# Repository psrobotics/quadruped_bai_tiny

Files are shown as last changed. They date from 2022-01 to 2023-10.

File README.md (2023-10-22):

# Quadruped_bai_tiny v1

Still working on detailed document.

quad_servo_cad

## Videos

[Walking](https://youtu.be/wHSh3s8Uc68)  /  [Jumping](https://youtu.be/LqSfARLMR58)  /  [Leg demo](https://www.youtube.com/watch?v=xufyeLivXR8)

## File Structure

* /hardware - CAD design

* /electronic - Motor driver, Main controller brd, Encoder brd, IIC bridge brd

* /sim - V-rep simulation, Kinematics, Dynamics

* /software - Firmware

## Reducer
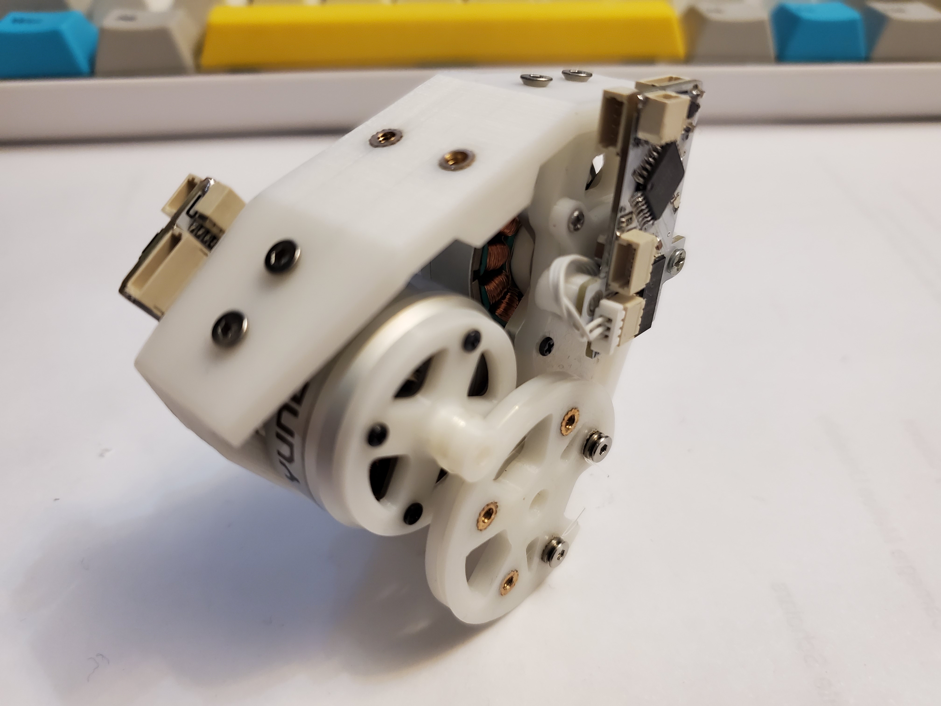
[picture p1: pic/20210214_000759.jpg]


## Leg Assembly
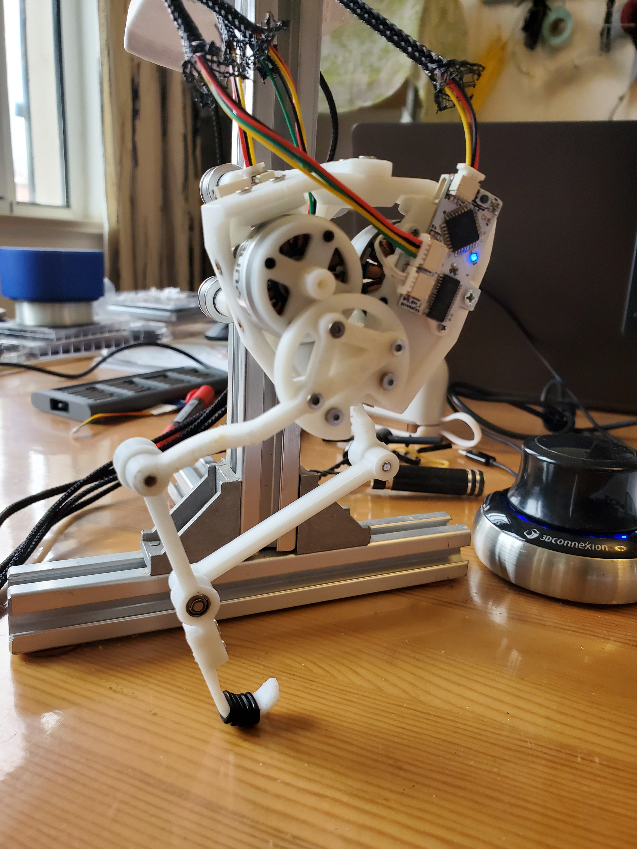
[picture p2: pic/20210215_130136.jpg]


## Body Assembly
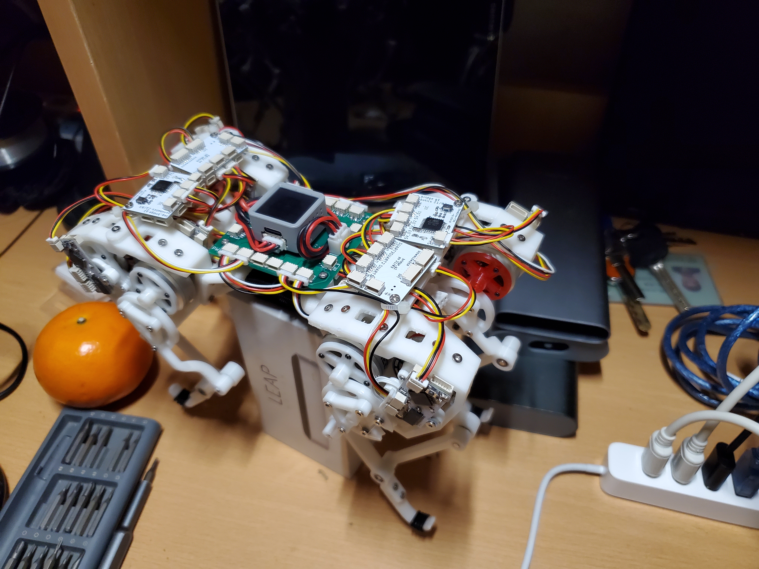
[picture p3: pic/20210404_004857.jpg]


## Motor Driver
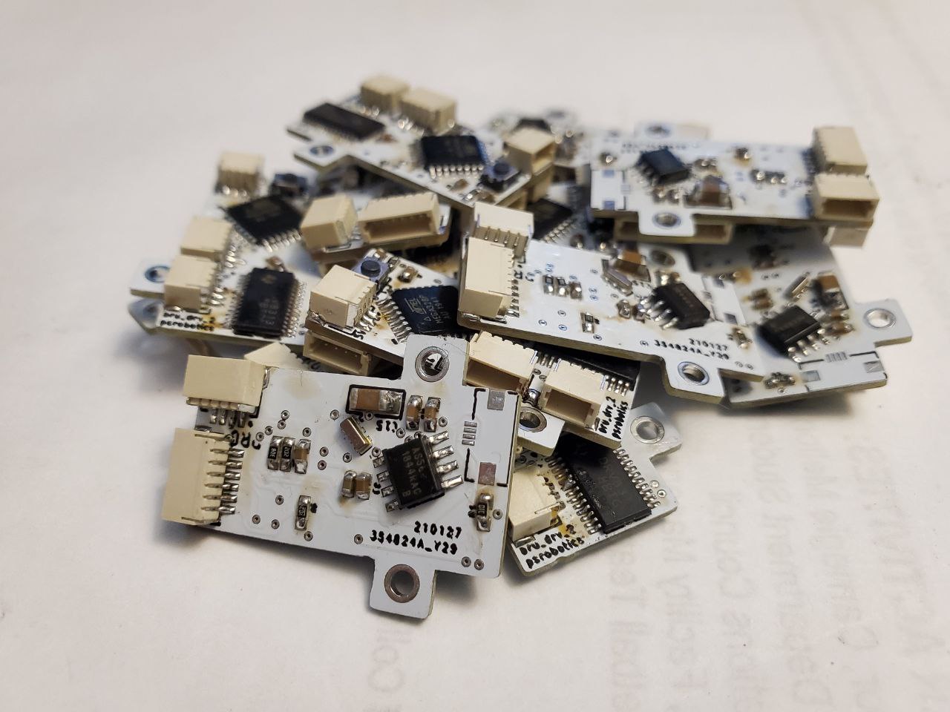
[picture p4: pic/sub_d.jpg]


## Main Controller
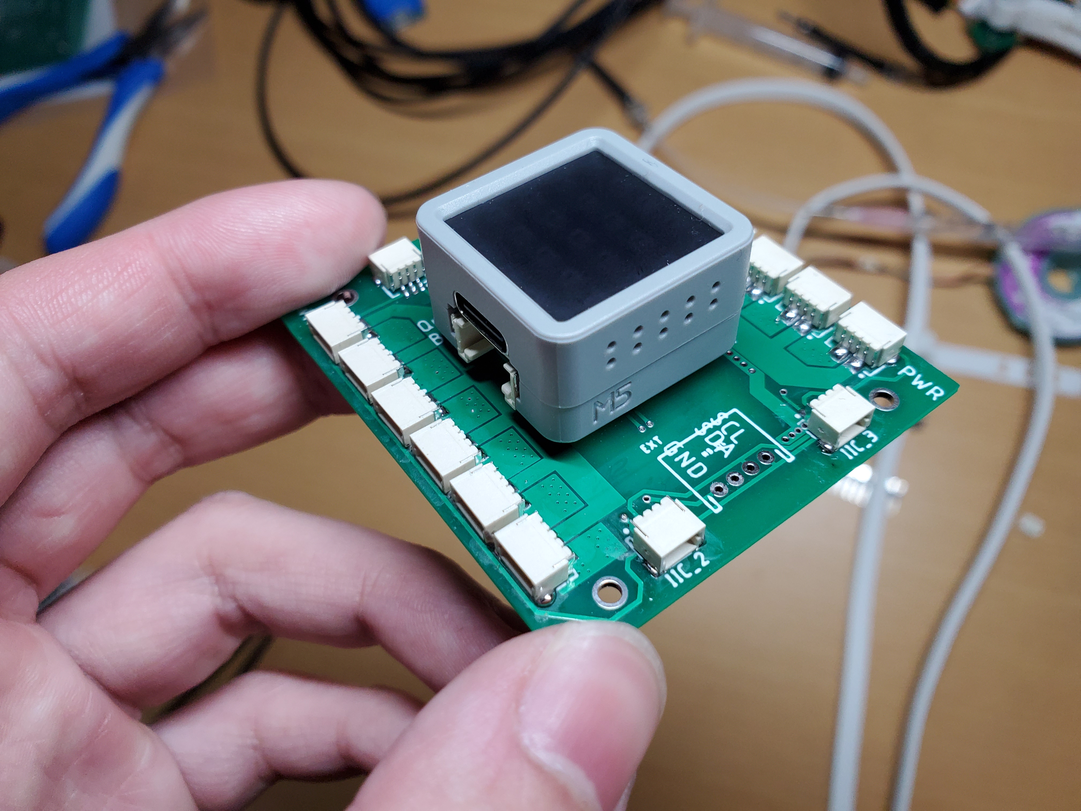
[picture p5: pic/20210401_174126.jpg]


## License
MIT License

## Contact
* Shuang Peng, {shuangpe}@usc.edu

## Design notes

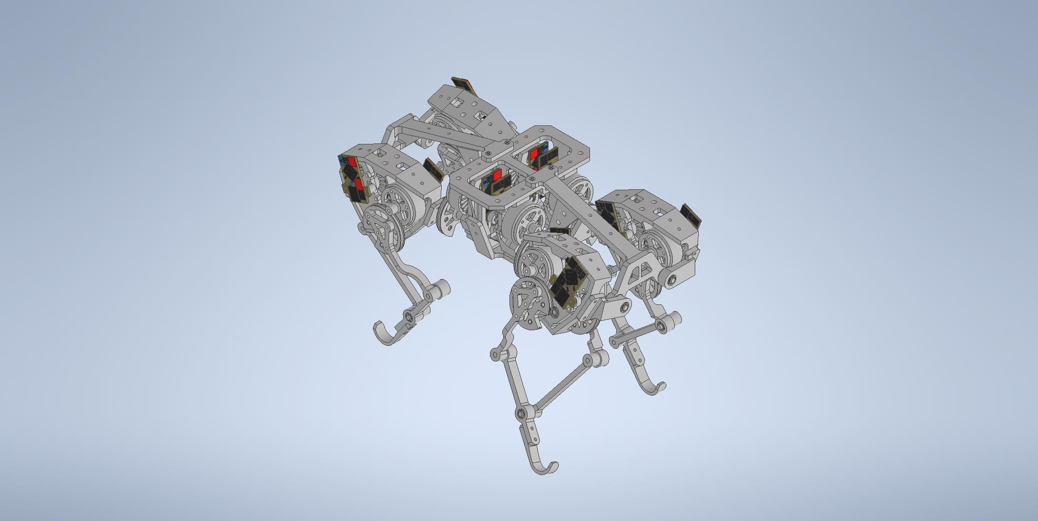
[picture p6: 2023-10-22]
hardware/pic_export/body_1.jpg

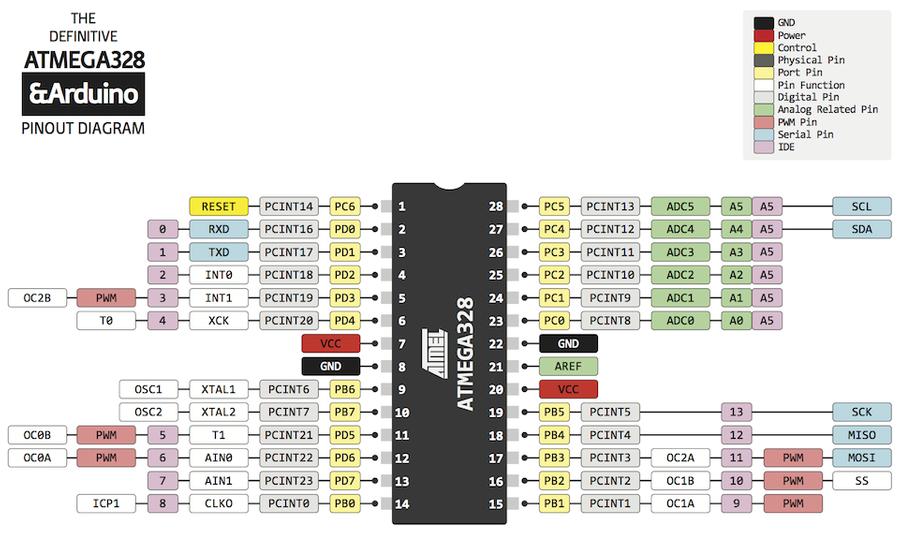
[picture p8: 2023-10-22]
electronic/ref/Atmega328P-PU-met-Arduino-Optiboot-(Arduino-Uno).jpg

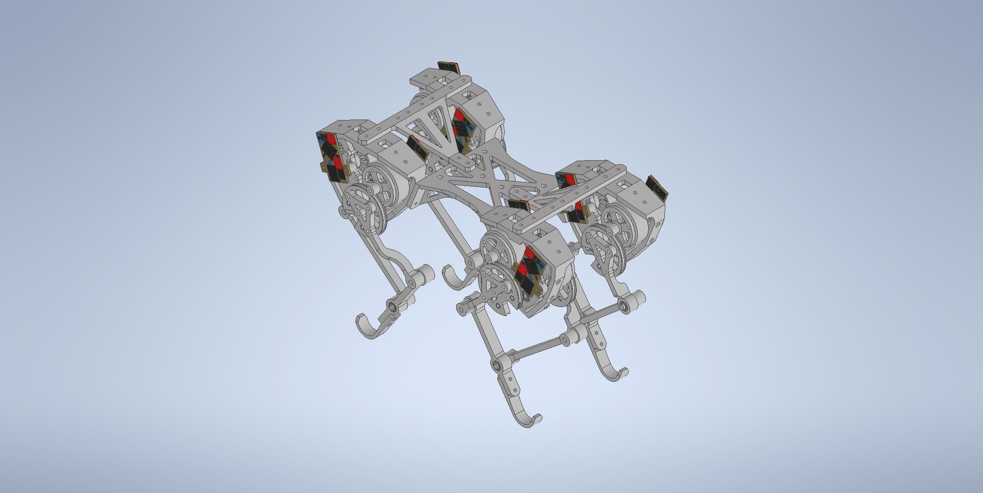
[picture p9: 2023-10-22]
hardware/pic_export/body_8d_1.jpg

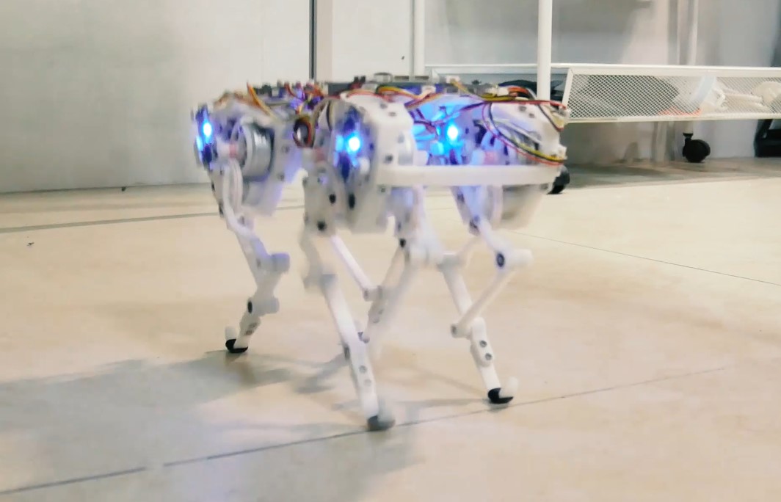
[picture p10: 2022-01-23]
pic/quad_bai_tiny_1.jpg

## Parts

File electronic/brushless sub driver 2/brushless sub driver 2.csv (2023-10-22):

RefDes | Value | Device | Package | Description | ARROW_EUROPE-PURCHASE-URL | AVAILABILITY | BUILT_BY | DESCRIPTION | DIGI-KEY_PART_NUMBER | DIGI-KEY_PURCHASE_URL | DIGIKEY-PURCHASE-URL | HEIGHT | MANUFACTURER_NAME | MANUFACTURER_PART_NUMBER | MF | MOUSER_PART_NUMBER | MOUSER_PRICE-STOCK | MP | PACKAGE | PRICE | PROD_ID | RS_PART_NUMBER | RS_PRICE-STOCK | SOURCELIBRARY | VALUE | VENDOR
5V | SM03B-SRSS-TB(LF)(SN) | SM03B-SRSS-TB(LF)(SN) | JST_SM03B-SRSS-TB(LF)(SN) | SH Series 3 Position 1 mm Pitch Surface Mount Side Entry Shrouded Header |  | Unavailable |  | Connector Header Surface Mount, Right Angle 3 position 0.039 _1.00mm_ |  |  |  |  |  |  | JST Sales |  |  | SM03B-SRSS-TB_LF__SN_ | None | None
C1 | 0.1uF | CAP0603-CAP | 0603-CAP | Capacitor
C2 | 0.1uF | CAP0603-CAP | 0603-CAP | Capacitor
C3 | 10nF | 10NF-0603-50V-10% | 0603 | 0.01uF/10nF/10,000pF ceramic capacitors |  |  |  |  |  |  |  |  |  |  |  |  |  |  |  |  | CAP-00867 |  |  |  | 10nF
C4 | 0.1uF | 0.1UF-0603-25V-(+80/-20%) | 0603 | 0.1µF ceramic capacitors |  |  |  |  |  |  |  |  |  |  |  |  |  |  |  |  | CAP-00810 |  |  |  | 0.1uF
C5 | 470nF | 470NF-0603-10V-10%-X5R | 0603 | 0.47uF/470nF ceramic capacitors |  |  |  |  |  |  |  |  |  |  |  |  |  |  |  |  | CAP-13216 |  |  |  | 470nF
C8 | 0.1uF | 0.1UF-0402-16V-10% | 0402 | 0.1µF ceramic capacitors |  |  |  |  |  |  |  |  |  |  |  |  |  |  |  |  | CAP-12416 |  |  |  | 0.1uF
C9 | 1.0uF | 1.0UF-0402-16V-10% | 0402 | 1µF ceramic capacitors |  |  |  |  |  |  |  |  |  |  |  |  |  |  |  |  | CAP-12417 |  |  |  | 1.0uF
C11 | 0.1uF | CAP0603-CAP | 0603-CAP | Capacitor
C15 | 100uf | C_1206 | C1206 | NON-POLARIZED CAP
D1 | b | LED0603 | LED-0603 | LED (Generic)
EN_EXT | 54550-0494 | 54550-0494 | CON4_1X4_DRB2_MOL |  |  |  | EMA_UL_Team |  |  |  |  |  |  | 54550-0494 |  |  |  |  |  |  |  |  |  | Molex_2010-01-01 |  | Molex Connector Corporation
IC1 | AS5600-ASOT | AS5600-ASOT | SOIC127P600X175-8N | Board Mount Hall Effect / Magnetic Sensors AS5600 Magnetic Sensor 12-Bit |  |  |  | Board Mount Hall Effect / Magnetic Sensors AS5600 Magnetic Sensor 12-Bit |  |  |  | 1.75mm | ams | AS5600-ASOT |  | 985-AS5600-ASOT | https://www.mouser.com/Search/Refine.aspx?Keyword=985-AS5600-ASOT
MOT | SM03B-SRSS-TB(LF)(SN) | SM03B-SRSS-TB(LF)(SN) | JST_SM03B-SRSS-TB(LF)(SN) | SH Series 3 Position 1 mm Pitch Surface Mount Side Entry Shrouded Header |  | Unavailable |  | Connector Header Surface Mount, Right Angle 3 position 0.039 _1.00mm_ |  |  |  |  |  |  | JST Sales |  |  | SM03B-SRSS-TB_LF__SN_ | None | None
NEFI | SM06B-SRSS-TB | SM06B-SRSS-TB | SM06B | CONN HEADER SH 6POS SIDE 1MM TIN Check prices |  | Bad |  | Connector Header Surface Mount, Right Angle 6 position 0.039 (1.00mm) |  |  |  |  |  |  | JST Sales |  |  | SM06B-SRSS-TB | None | None
PRO | SM04B-SRSS-TB(LF)(SN) | SM04B-SRSS-TB(LF)(SN) | JST_SM04B-SRSS-TB(LF)(SN) | SH Series 1.0 mm Pitch 2 Position Single Row Side Entry Shrouded Header Check prices | https://snapeda.com/shop?store=Arrow+Europe&id=557466 | Good |  | Connector Header Surface Mount, Right Angle 4 position 0.039 (1.00mm) |  |  | https://snapeda.com/shop?store=DigiKey&id=557466 |  |  |  | JST Sales |  |  | SM04B-SRSS-TB(LF)(SN) | None | None
PWR | SM04B-SRSS-TB(LF)(SN) | SM04B-SRSS-TB(LF)(SN) | JST_SM04B-SRSS-TB(LF)(SN) | SH Series 1.0 mm Pitch 2 Position Single Row Side Entry Shrouded Header Check prices | https://snapeda.com/shop?store=Arrow+Europe&id=557466 | Good |  | Connector Header Surface Mount, Right Angle 4 position 0.039 (1.00mm) |  |  | https://snapeda.com/shop?store=DigiKey&id=557466 |  |  |  | JST Sales |  |  | SM04B-SRSS-TB(LF)(SN) | None | None
Q2 | 16mhz | RESONATOR-MURATACST_CE | RESONATOR_MURATA2 | Murata ceramic Resonator ceralock" CSTCE series"
R1 | 10k | 10KOHM-0603-1/10W-1% | 0603 | 10kΩ resistor |  |  |  |  |  |  |  |  |  |  |  |  |  |  |  |  | RES-00824 |  |  |  | 10k
R2 | 10K | RESISTOR0603-RES | 0603-RES | Resistor
R3 | 2.2k | RESISTOR0603-RES | 0603-RES | Resistor
R4 | 0 | R_0603 | R0603 | RESISTOR
R5 | 3K | RESISTOR0603-RES | 0603-RES | Resistor
R8 | 2.2k | RESISTOR0603-RES | 0603-RES | Resistor
S2 | MOMENTARY-SWITCH-SPST-SMD-RIGHT-ANGLE | MOMENTARY-SWITCH-SPST-SMD-RIGHT-ANGLE | TACTILE_SWITCH_SMD_RIGHT_ANGLE | Momentary Switch (Pushbutton) - SPST |  |  |  |  |  |  |  |  |  |  |  |  |  |  |  |  | COMP-12265
U1 | DRV8313PWP | DRV8313PWP | SOP28P65_970X640X120L60X24T483X275N | 2.5A Three Phase Brushless DC Motor Driver (PWM Ctrl) 28-HTSSOP -40 to 85 |  |  |  | 2.5A Three Phase Brushless DC Motor Driver _PWM Ctrl_ 28-HTSSOP -40 to 85 | 296-35540-5-ND | https://www.digikey.com.cn/product-detail/zh/texas-instruments/DRV8313PWP/296-35540-5-ND/3790947 |  |  |  |  | Texas Instruments |  |  | DRV8313PWP | HTSSOP-28 Texas Instruments
U3 | ATMEGA328 | ATMEGA168 | TQFP32-08

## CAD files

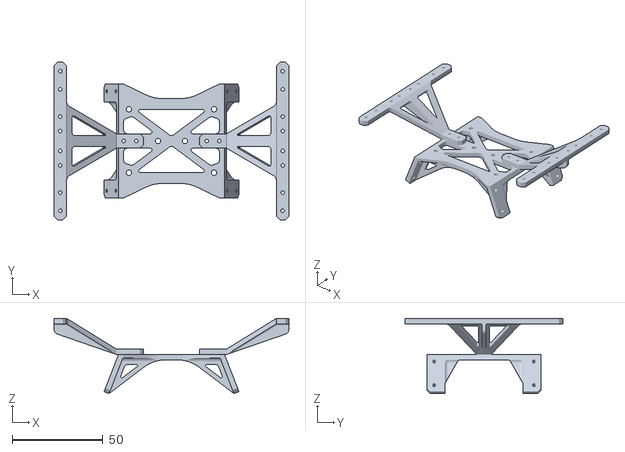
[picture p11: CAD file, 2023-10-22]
hardware/sim_mod/8dof_body.stl
129.8 x 87.0 x 41.5

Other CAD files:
hardware/8dof_body.iam
hardware/OldVersions/8dof_body.0001.iam
hardware/OldVersions/bearing_3_6_2.0007.ipt
hardware/OldVersions/bearing_3_6_2_MIR.0001.ipt
hardware/OldVersions/body_1.0043.iam
hardware/OldVersions/body_8d_1.0019.iam
hardware/OldVersions/body_8d_wid_1.0006.iam
hardware/OldVersions/body_conn_1.0007.ipt
hardware/OldVersions/body_conn_1_MIR.0002.ipt
hardware/OldVersions/body_conn_2.0006.ipt
hardware/OldVersions/body_conn_2_MIR.0002.ipt
hardware/OldVersions/body_linker_1_8d.0004.ipt
hardware/OldVersions/body_linker_1_wid_8d.0008.ipt
hardware/OldVersions/body_linker_2_8d.0004.ipt
hardware/OldVersions/body_linker_2_8d_wid.0004.ipt
hardware/OldVersions/body_shell_1.0009.ipt
hardware/OldVersions/body_shell_2.0008.ipt
hardware/OldVersions/cable_shell_1.0001.ipt
hardware/OldVersions/en_shell_1.0003.ipt
hardware/OldVersions/enc_holder_1.0004.ipt
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

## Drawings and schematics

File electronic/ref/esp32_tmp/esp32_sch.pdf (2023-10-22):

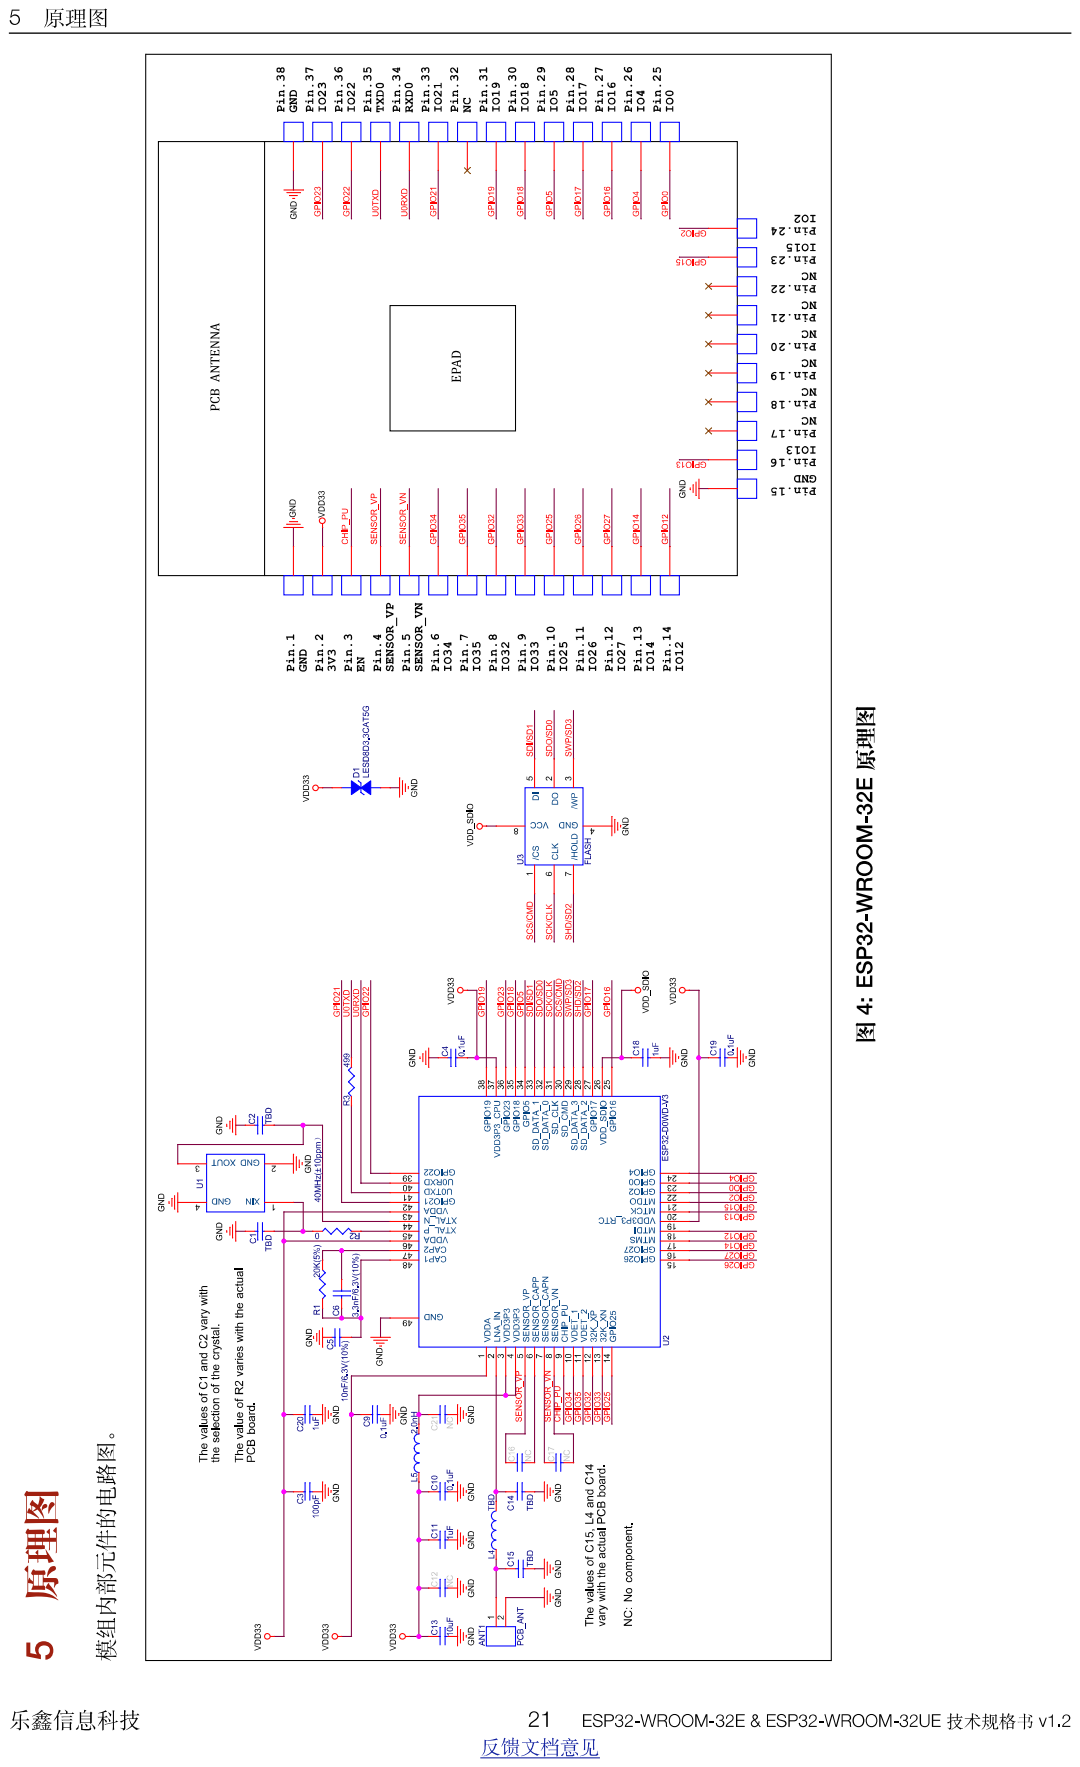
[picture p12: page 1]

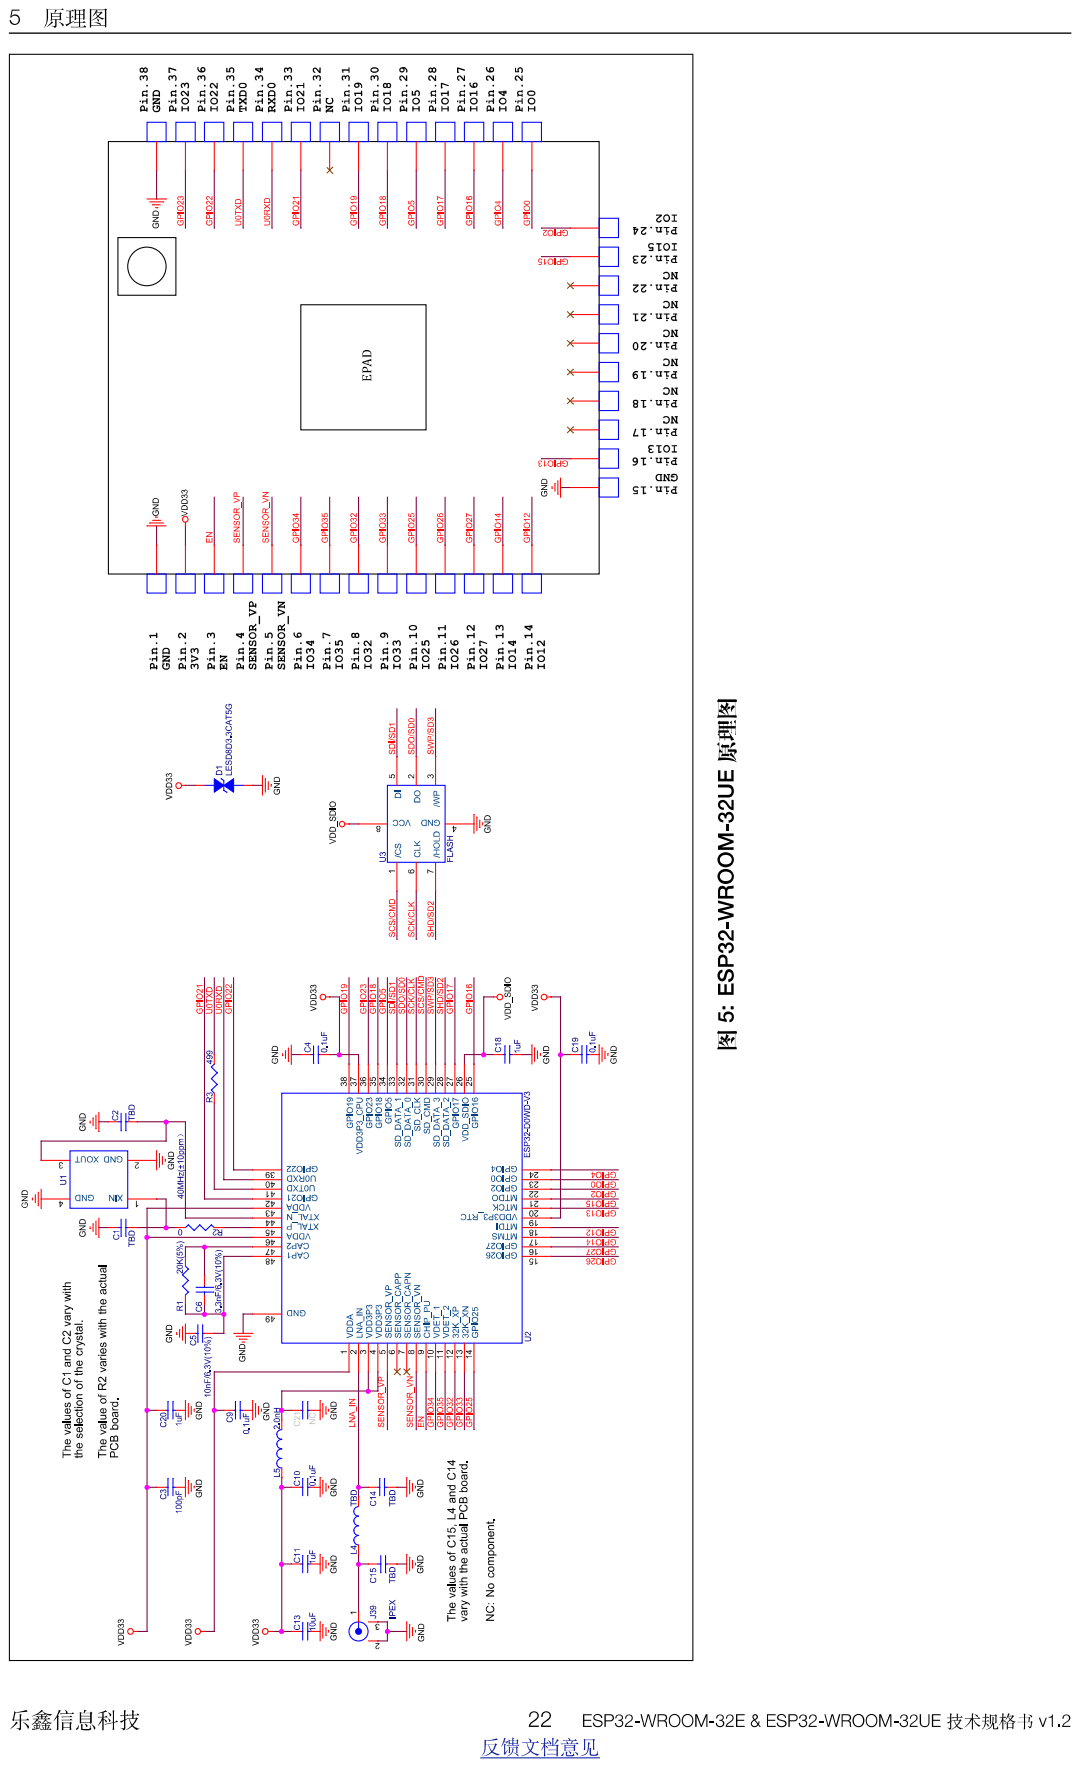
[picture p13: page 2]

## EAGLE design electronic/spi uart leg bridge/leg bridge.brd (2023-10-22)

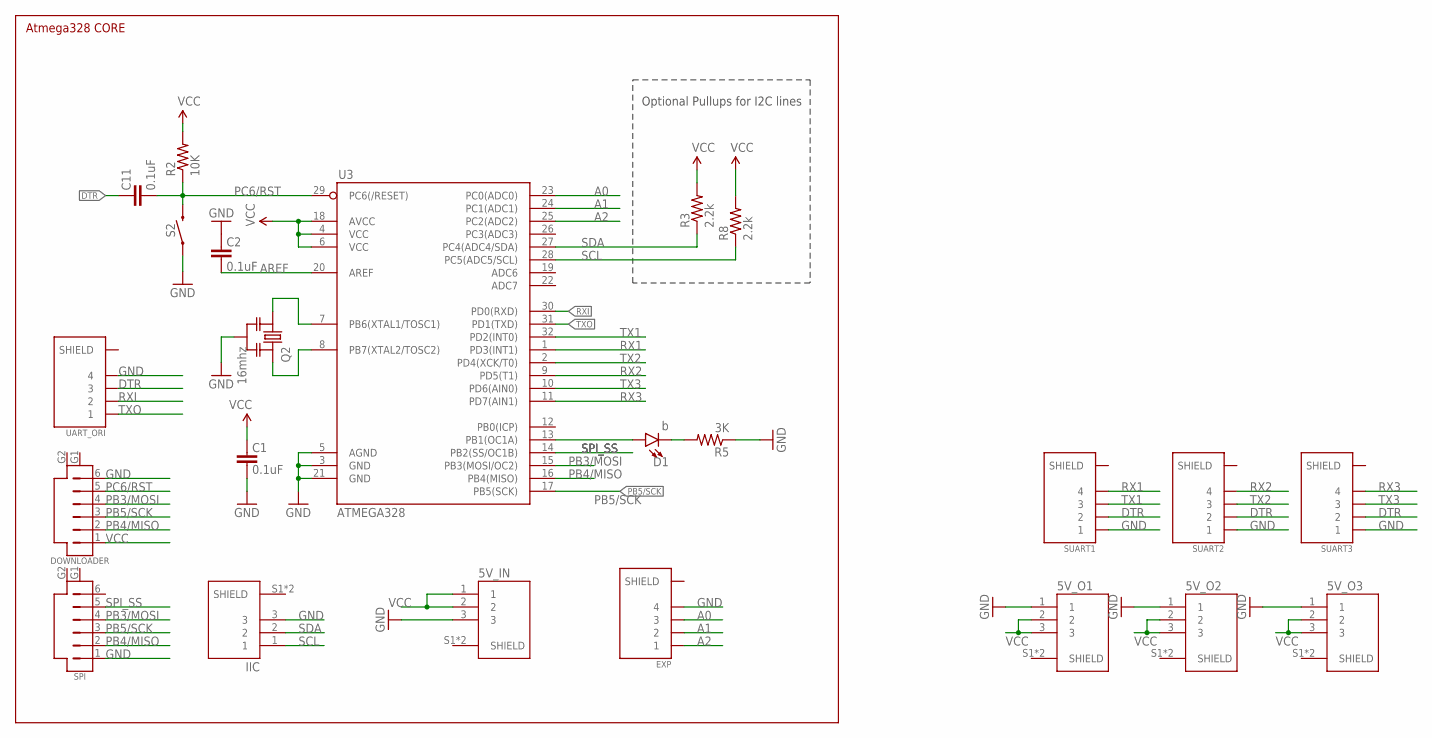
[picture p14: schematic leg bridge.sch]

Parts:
5V_IN, 5V_O1, 5V_O2, 5V_O3: SM03B-SRSS-TB(LF)(SN); JST_SM03B-SRSS-TB(LF)(SN)
C1, C2, C11: 0.1uF; 0603-CAP
D1: b; LED-0603
DOWNLOADER: SM06B-SRSS-TB; SM06B
EXP: SM04B-SRSS-TB(LF)(SN); JST_SM04B-SRSS-TB(LF)(SN)
IIC: SM03B-SRSS-TB(LF)(SN); JST_SM03B-SRSS-TB(LF)(SN)
Q2: 16mhz; RESONATOR_MURATA2
R2: 10K; 0603-RES
R3, R8: 2.2k; 0603-RES
R5: 3K; 0603-RES
S2: MOMENTARY-SWITCH-SPST-SMD-RIGHT-ANGLE; TACTILE_SWITCH_SMD_RIGHT_ANGLE
SPI: SM06B-SRSS-TB; SM06B
SUART1, SUART2, SUART3: SM04B-SRSS-TB(LF)(SN); JST_SM04B-SRSS-TB(LF)(SN)
U3: ATMEGA328; TQFP32-08
UART_ORI: SM04B-SRSS-TB(LF)(SN); JST_SM04B-SRSS-TB(LF)(SN)

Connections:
A0: EXP.3, U3.23 (PC0(ADC0))
A1: EXP.2, U3.24 (PC1(ADC1))
A2: EXP.1, U3.25 (PC2(ADC2))
AREF: C2.1, U3.20 (AREF)
DTR: C11.2, SUART1.2, SUART2.2, SUART3.2, UART_ORI.3
GND: 5V_IN.3, 5V_O1.1, 5V_O2.1, 5V_O3.1, C1.1, C2.2, DOWNLOADER.6, EXP.4, IIC.3, Q2.2, R5.1, S2.1, SPI.1, SUART1.1, SUART2.1, SUART3.1, U3.3 (GND), U3.5 (AGND), U3.21 (GND), UART_ORI.4
unnamed: Q2.1, U3.7 (PB6(XTAL1/TOSC1))
unnamed: Q2.3, U3.8 (PB7(XTAL2/TOSC2))
unnamed: D1.A, U3.13 (PB1(OC1A))
unnamed: D1.C, R5.2
PB3/MOSI: DOWNLOADER.4, SPI.4, U3.15 (PB3(MOSI/OC2))
PB4/MISO: DOWNLOADER.2, SPI.2, U3.16 (PB4(MISO))
PB5/SCK: DOWNLOADER.3, SPI.3, U3.17 (PB5(SCK))
PC6/RST: C11.1, DOWNLOADER.5, R2.1, S2.2, U3.29 (PC6(/RESET))
RX1: SUART1.4, U3.1 (PD3(INT1))
RX2: SUART2.4, U3.9 (PD5(T1))
RX3: SUART3.4, U3.11 (PD7(AIN1))
RXI: U3.30 (PD0(RXD)), UART_ORI.2
SCL: IIC.1, R8.1, U3.28 (PC5(ADC5/SCL))
SDA: IIC.2, R3.1, U3.27 (PC4(ADC4/SDA))
SPI_SS: SPI.5, U3.14 (PB2(SS/OC1B))
TX1: SUART1.3, U3.32 (PD2(INT0))
TX2: SUART2.3, U3.2 (PD4(XCK/T0))
TX3: SUART3.3, U3.10 (PD6(AIN0))
TXO: U3.31 (PD1(TXD)), UART_ORI.1
VCC: 5V_IN.1, 5V_IN.2, 5V_O1.2, 5V_O1.3, 5V_O2.2, 5V_O2.3, 5V_O3.2, 5V_O3.3, C1.2, DOWNLOADER.1, R2.2, R3.2, R8.2, U3.4 (VCC), U3.6 (VCC), U3.18 (AVCC)

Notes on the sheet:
Optional Pullups for I2C lines
Atmega328 CORE

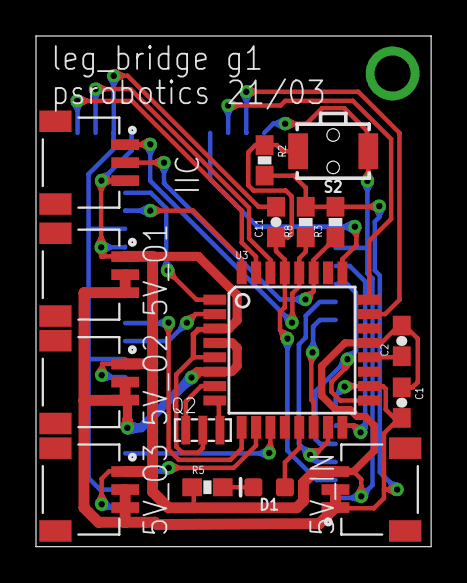
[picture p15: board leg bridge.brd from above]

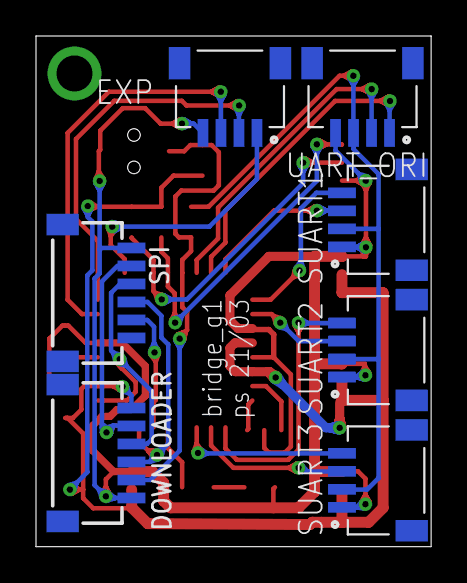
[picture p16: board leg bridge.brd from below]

Board: 2 copper layers, 22.0 x 28.4 mm, 23 parts (7 on the bottom side), 26 nets.

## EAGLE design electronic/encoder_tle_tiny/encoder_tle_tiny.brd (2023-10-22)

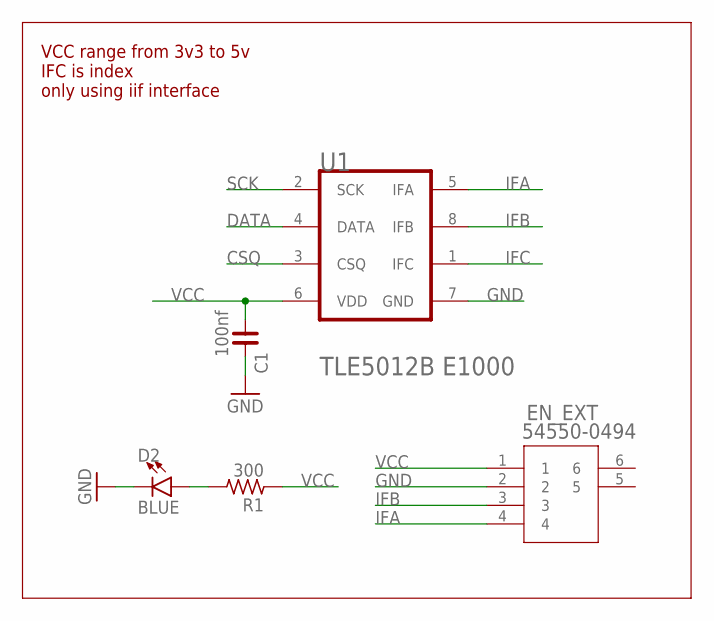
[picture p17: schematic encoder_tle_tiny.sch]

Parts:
C1: 100nf; C0603
D2: BLUE; LED-0603
EN_EXT: 54550-0494; CON4_1X4_DRB2_MOL
R1: 300; R0603
U1: INFINEON_TLE5012B_E1000INFINEON_TLE5012B_E1000_0_1; INFINEON_TLE5012B_E1000_1

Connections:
CSQ: U1.3 (CSQ)
DATA: U1.4 (DATA)
GND: C1.2, D2.C, EN_EXT.2, U1.7 (GND)
IFA: EN_EXT.4, U1.5 (IFA)
IFB: EN_EXT.3, U1.8 (IFB)
IFC: U1.1 (IFC)
unnamed: D2.A, R1.2
SCK: U1.2 (SCK)
VCC: C1.1, EN_EXT.1, R1.1, U1.6 (VDD)

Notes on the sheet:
VCC range from 3v3 to 5v IFC is index only using iif interface

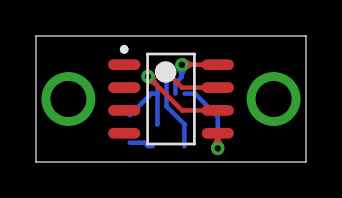
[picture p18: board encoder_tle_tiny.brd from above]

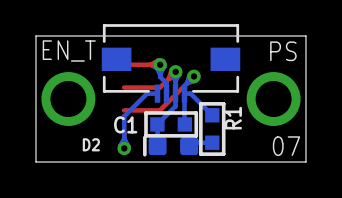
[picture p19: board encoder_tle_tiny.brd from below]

Board: 2 copper layers, 15.0 x 7.0 mm, 5 parts (4 on the bottom side), 5 nets.

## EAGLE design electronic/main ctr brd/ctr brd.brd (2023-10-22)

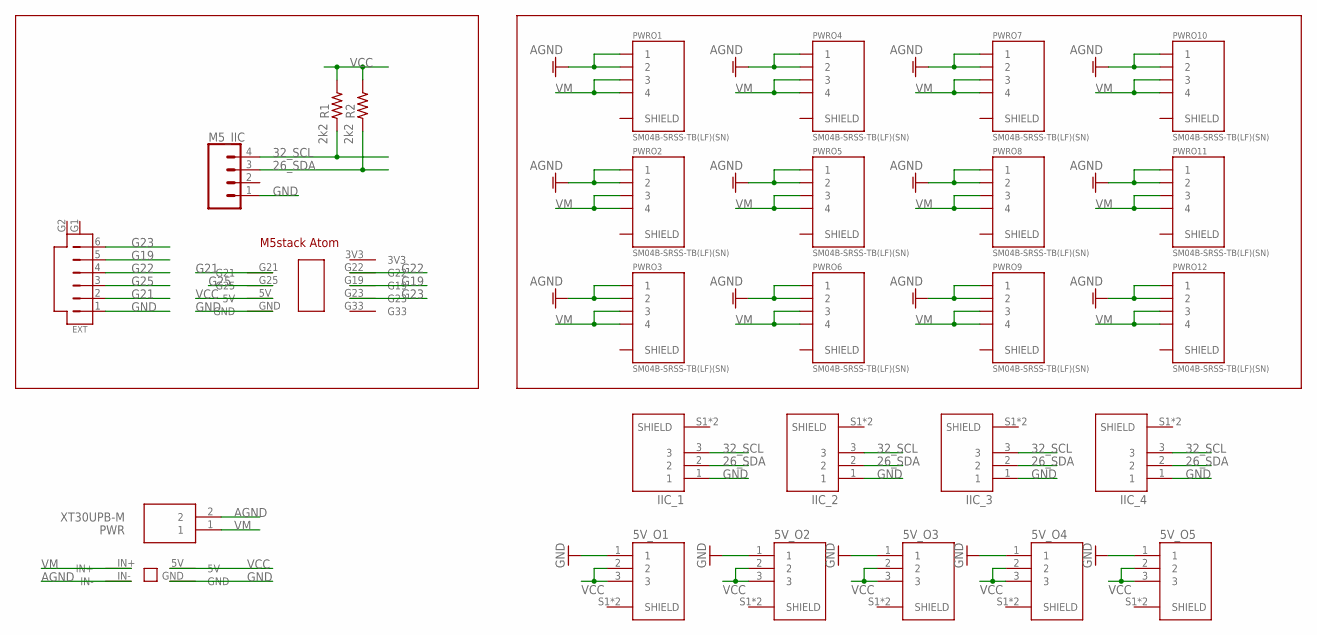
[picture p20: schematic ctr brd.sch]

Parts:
5V_O1, 5V_O2, 5V_O3, 5V_O4, 5V_O5: SM03B-SRSS-TB(LF)(SN); JST_SM03B-SRSS-TB(LF)(SN)
EXT: SM06B-SRSS-TB; SM06B
IIC_1, IIC_2, IIC_3, IIC_4: SM03B-SRSS-TB(LF)(SN); JST_SM03B-SRSS-TB(LF)(SN)
M5_IIC: CONN_04JST-PTH; JST-4-PTH
PWR: XT30UPB-M; SHDR2W160P0X500_1X2_1020X520X1
PWRO1, PWRO2, PWRO3, PWRO4, PWRO5, PWRO6, PWRO7, PWRO8, PWRO9, PWRO10, PWRO11, PWRO12: SM04B-SRSS-TB(LF)(SN); JST_SM04B-SRSS-TB(LF)(SN)
R1, R2: 2k2; R0603
U$1: M5STACK_ATOM
U$2: 5V_STAB

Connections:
26_SDA: IIC_1.2, IIC_2.2, IIC_3.2, IIC_4.2, M5_IIC.3, R2.1
32_SCL: IIC_1.3, IIC_2.3, IIC_3.3, IIC_4.3, M5_IIC.4, R1.1
AGND: PWR.2, PWRO1.1, PWRO1.2, PWRO2.1, PWRO2.2, PWRO3.1, PWRO3.2, PWRO4.1, PWRO4.2, PWRO5.1, PWRO5.2, PWRO6.1, PWRO6.2, PWRO7.1, PWRO7.2, PWRO8.1, PWRO8.2, PWRO9.1, PWRO9.2, PWRO10.1, PWRO10.2, PWRO11.1, PWRO11.2, PWRO12.1, PWRO12.2, U$2.IN-
G19: EXT.5, U$1.G19
G21: EXT.2, U$1.G21
G22: EXT.4, U$1.G22
G23: EXT.6, U$1.G23
G25: EXT.3, U$1.G25
GND: 5V_O1.1, 5V_O2.1, 5V_O3.1, 5V_O4.1, 5V_O5.1, EXT.1, IIC_1.1, IIC_2.1, IIC_3.1, IIC_4.1, M5_IIC.1, U$1.GND, U$2.GND
VCC: 5V_O1.2, 5V_O1.3, 5V_O2.2, 5V_O2.3, 5V_O3.2, 5V_O3.3, 5V_O4.2, 5V_O4.3, 5V_O5.2, 5V_O5.3, R1.2, R2.2, U$1.5V, U$2.5V
VM: PWR.1, PWRO1.3, PWRO1.4, PWRO2.3, PWRO2.4, PWRO3.3, PWRO3.4, PWRO4.3, PWRO4.4, PWRO5.3, PWRO5.4, PWRO6.3, PWRO6.4, PWRO7.3, PWRO7.4, PWRO8.3, PWRO8.4, PWRO9.3, PWRO9.4, PWRO10.3, PWRO10.4, PWRO11.3, PWRO11.4, PWRO12.3, PWRO12.4, U$2.IN+

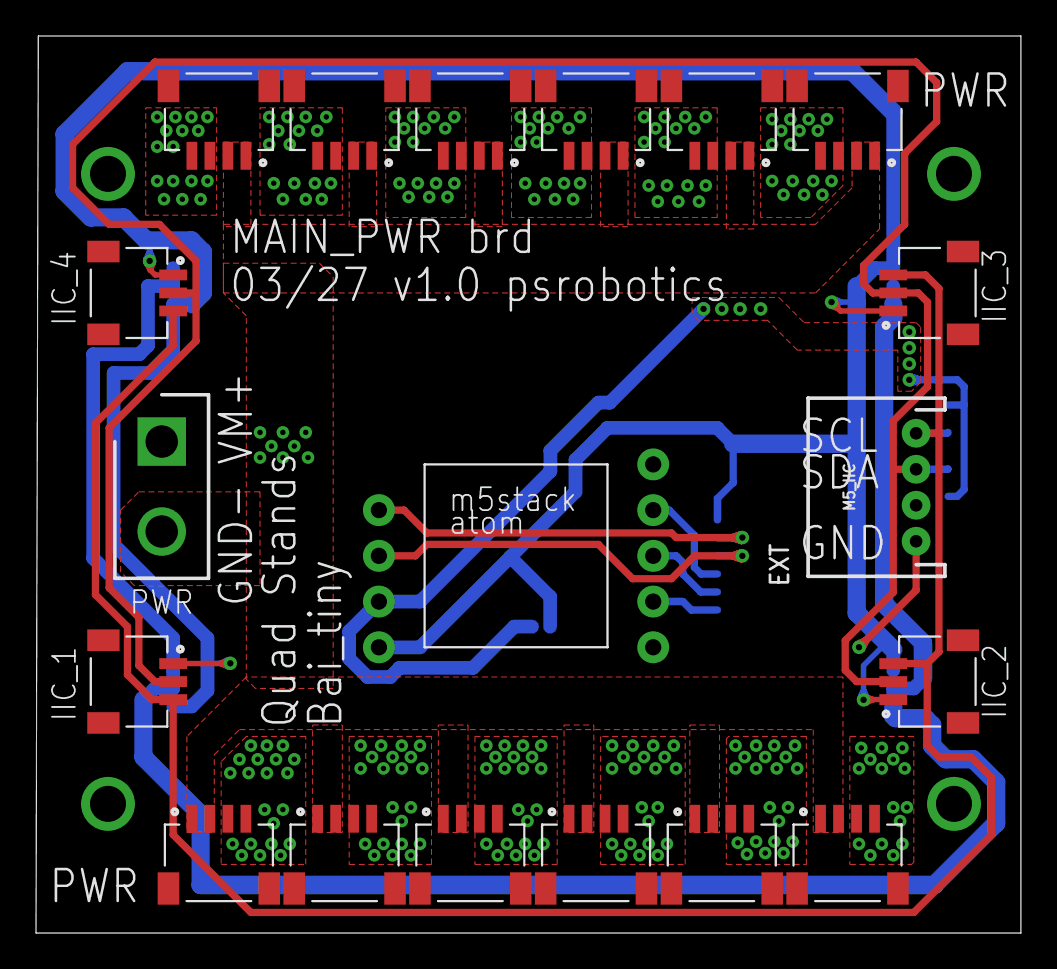
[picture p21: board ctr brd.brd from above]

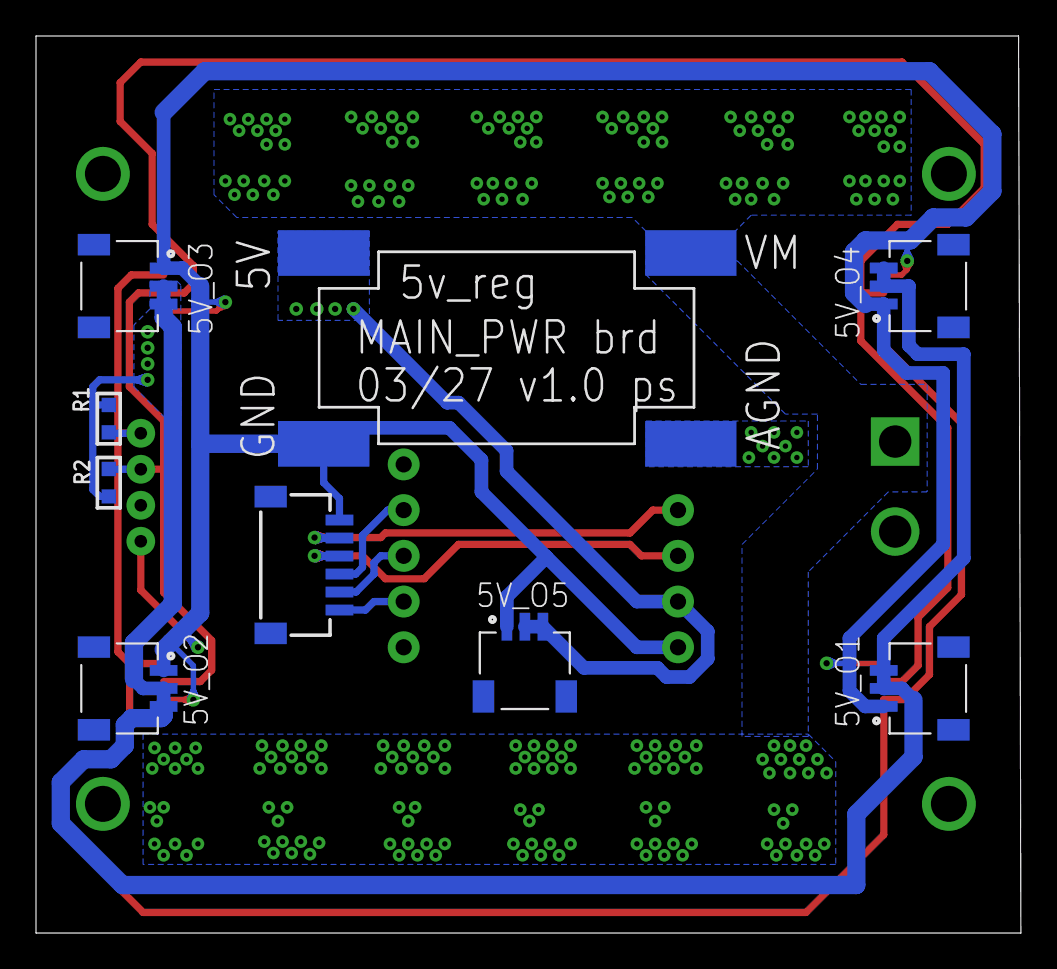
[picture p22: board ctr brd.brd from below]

Board: 2 copper layers, 54.7 x 49.8 mm, 28 parts (9 on the bottom side), 11 nets.

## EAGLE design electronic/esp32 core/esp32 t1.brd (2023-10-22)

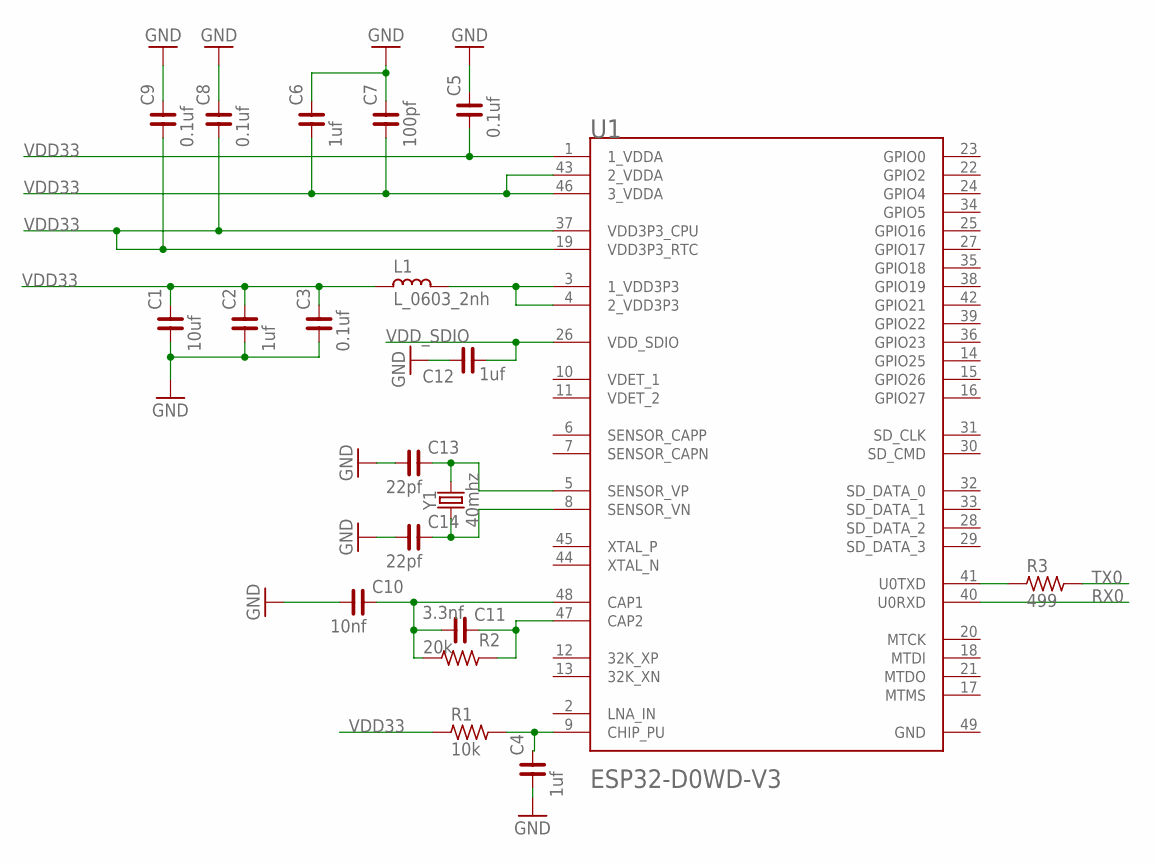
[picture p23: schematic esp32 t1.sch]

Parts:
C1: 10uf; C0603
C2, C4, C6, C12: 1uf; C0603
C3, C5, C8, C9: 0.1uf; C0603
C7: 100pf; C0603
C10: 10nf; C0603
C11: 3.3nf; C0603
C13, C14: 22pf; C0603
L1: L_0603_2nh; L0603
R1: 10k; R0603
R2: 20k; R0603
R3: 499; R0603
U1: ESPRESSIF_SYSTEMS_ESP32-D0WD-V3ESPRESSIF_SYSTEMS_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; ESPRESSIF_SYSTEMS_ESP32-D0WD-V3_0
Y1: 40mhz; CRYSTAL-SMD-3.2X1.5MM

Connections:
GND: C1.1, C2.1, C3.1, C4.1, C5.2, C6.2, C7.2, C8.2, C9.2, C10.1, C12.2, C13.1, C14.1, U1.49 (GND)
unnamed: C4.2, R1.2, U1.9 (CHIP_PU)
unnamed: L1.1, U1.3 (1_VDD3P3), U1.4 (2_VDD3P3)
unnamed: C10.2, C11.1, R2.1, U1.48 (CAP1)
unnamed: C11.2, R2.2, U1.47 (CAP2)
unnamed: C13.2, U1.5 (SENSOR_VP), Y1.P$2 (2)
unnamed: R3.1, U1.41 (U0TXD)
unnamed: C14.2, U1.8 (SENSOR_VN), Y1.P$1 (1)
RX0: U1.40 (U0RXD)
TX0: R3.2
VDD33: C1.2, C2.2, C3.2, C5.1, C6.1, C7.1, C8.1, C9.1, L1.2, R1.1, U1.1 (1_VDDA), U1.19 (VDD3P3_RTC), U1.37 (VDD3P3_CPU), U1.43 (2_VDDA), U1.46 (3_VDDA)
VDD_SDIO: C12.1, U1.26 (VDD_SDIO)
VDET_1: U1.10 (VDET_1)
VDET_2: U1.11 (VDET_2)

Board: 2 copper layers, 20 parts (0 on the bottom side), 10 nets, no tracks yet.

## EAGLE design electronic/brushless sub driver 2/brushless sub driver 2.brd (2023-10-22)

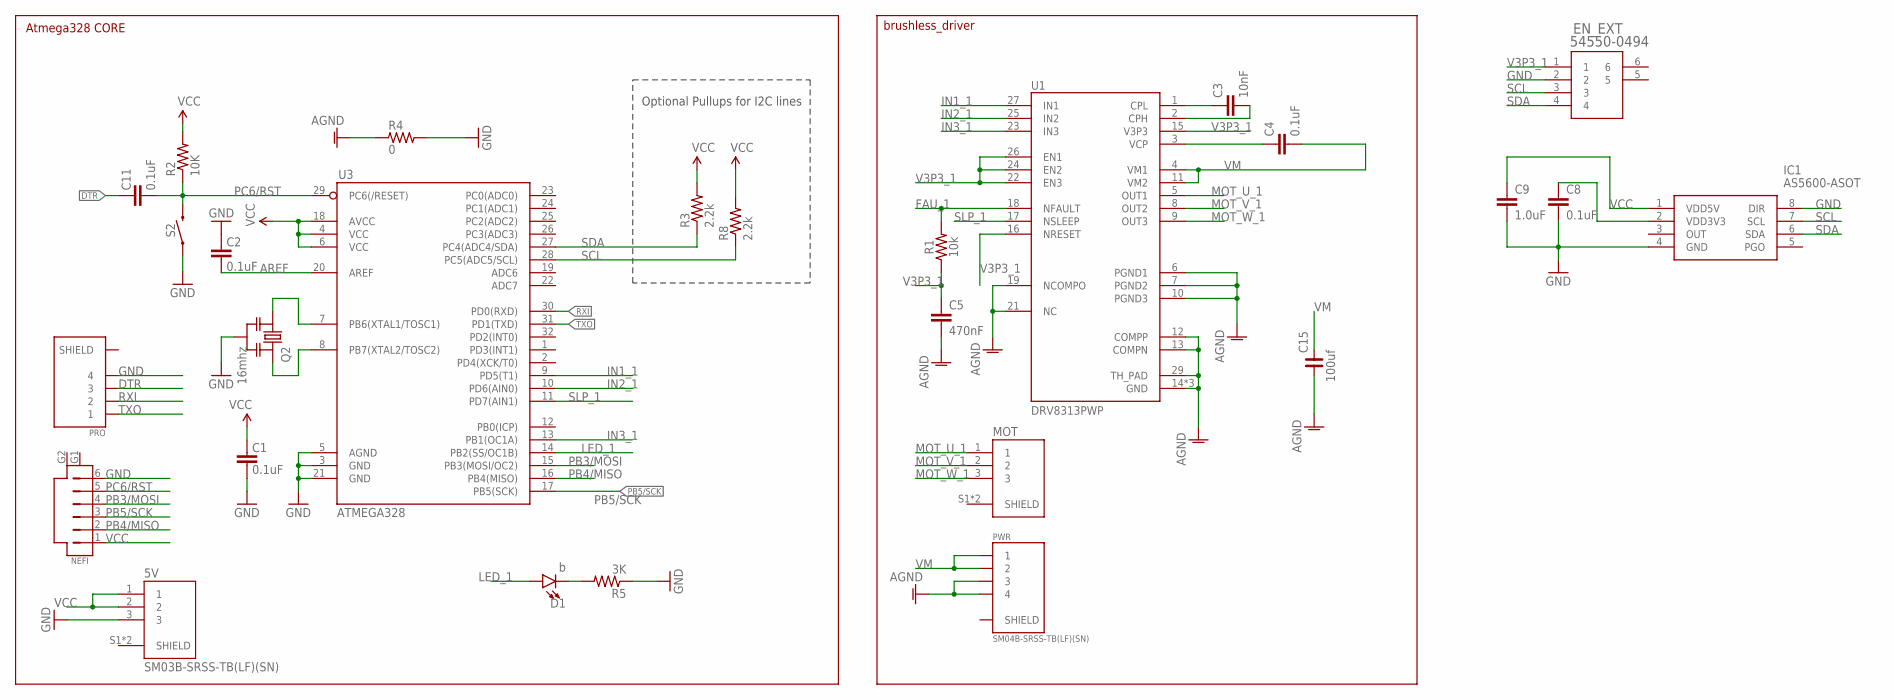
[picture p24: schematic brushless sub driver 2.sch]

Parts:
5V: SM03B-SRSS-TB(LF)(SN); JST_SM03B-SRSS-TB(LF)(SN)
C1, C2, C11: 0.1uF; 0603-CAP
C3: 10nF; 0603
C4: 0.1uF; 0603
C5: 470nF; 0603
C8: 0.1uF; 0402
C9: 1.0uF; 0402
C15: 100uf; C1206
D1: b; LED-0603
EN_EXT: 54550-0494; CON4_1X4_DRB2_MOL
IC1: AS5600-ASOT; SOIC127P600X175-8N
MOT: SM03B-SRSS-TB(LF)(SN); JST_SM03B-SRSS-TB(LF)(SN)
NEFI: SM06B-SRSS-TB; SM06B
PRO: SM04B-SRSS-TB(LF)(SN); JST_SM04B-SRSS-TB(LF)(SN)
PWR: SM04B-SRSS-TB(LF)(SN); JST_SM04B-SRSS-TB(LF)(SN)
Q2: 16mhz; RESONATOR_MURATA2
R1: 10k; 0603
R2: 10K; 0603-RES
R3, R8: 2.2k; 0603-RES
R4: 0; R0603
R5: 3K; 0603-RES
S2: MOMENTARY-SWITCH-SPST-SMD-RIGHT-ANGLE; TACTILE_SWITCH_SMD_RIGHT_ANGLE
U1: DRV8313PWP; SOP28P65_970X640X120L60X24T483X275N
U3: ATMEGA328; TQFP32-08

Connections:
AGND: C5.2, C15.1, PWR.3, PWR.4, R4.1, U1.6 (PGND1), U1.7 (PGND2), U1.10 (PGND3), U1.12 (COMPP), U1.13 (COMPN), U1.14 (GND), U1.19 (NCOMPO), U1.20 (GND), U1.21 (NC), U1.28 (GND), U1.29 (TH_PAD)
AREF: C2.1, U3.20 (AREF)
DTR: C11.2, PRO.3
FAU_1: R1.2, U1.18 (NFAULT)
GND: 5V.3, C1.1, C2.2, C8.2, C9.2, EN_EXT.2, IC1.4 (GND), IC1.8 (DIR), NEFI.6, PRO.4, Q2.2, R4.2, R5.1, S2.1, U3.3 (GND), U3.5 (AGND), U3.21 (GND)
IN1_1: U1.27 (IN1), U3.9 (PD5(T1))
IN2_1: U1.25 (IN2), U3.10 (PD6(AIN0))
IN3_1: U1.23 (IN3), U3.13 (PB1(OC1A))
LED_1: D1.A, U3.14 (PB2(SS/OC1B))
MOT_U_1: MOT.1, U1.5 (OUT1)
MOT_V_1: MOT.2, U1.8 (OUT2)
MOT_W_1: MOT.3, U1.9 (OUT3)
unnamed: Q2.1, U3.7 (PB6(XTAL1/TOSC1))
unnamed: Q2.3, U3.8 (PB7(XTAL2/TOSC2))
unnamed: C3.1, U1.1 (CPL)
unnamed: C3.2, U1.2 (CPH)
unnamed: C4.1, U1.3 (VCP)
unnamed: C8.1, IC1.2 (VDD3V3)
unnamed: D1.C, R5.2
PB3/MOSI: NEFI.4, U3.15 (PB3(MOSI/OC2))
PB4/MISO: NEFI.2, U3.16 (PB4(MISO))
PB5/SCK: NEFI.3, U3.17 (PB5(SCK))
PC6/RST: C11.1, NEFI.5, R2.1, S2.2, U3.29 (PC6(/RESET))
RXI: PRO.2, U3.30 (PD0(RXD))
SCL: EN_EXT.3, IC1.7 (SCL), R8.1, U3.28 (PC5(ADC5/SCL))
SDA: EN_EXT.4, IC1.6 (SDA), R3.1, U3.27 (PC4(ADC4/SDA))
SLP_1: U1.17 (NSLEEP), U3.11 (PD7(AIN1))
TXO: PRO.1, U3.31 (PD1(TXD))
V3P3_1: C5.1, EN_EXT.1, R1.1, U1.15 (V3P3), U1.16 (NRESET), U1.22 (EN3), U1.24 (EN2), U1.26 (EN1)
VCC: 5V.1, 5V.2, C1.2, C9.1, IC1.1 (VDD5V), NEFI.1, R2.2, R3.2, R8.2, U3.4 (VCC), U3.6 (VCC), U3.18 (AVCC)
VM: C4.2, C15.2, PWR.1, PWR.2, U1.4 (VM1), U1.11 (VM2)

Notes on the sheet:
Optional Pullups for I2C lines
Atmega328 CORE
brushless_driver

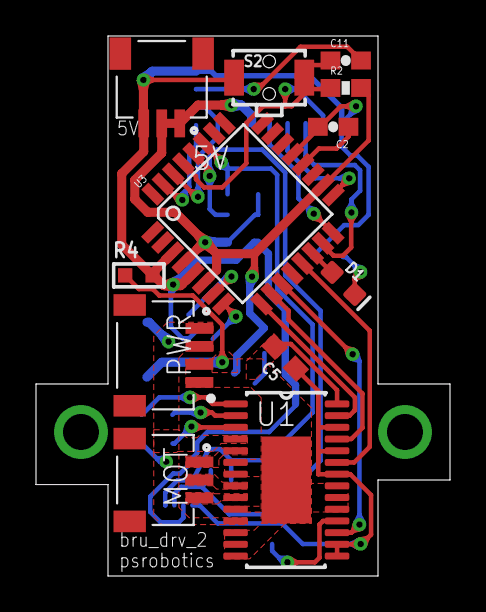
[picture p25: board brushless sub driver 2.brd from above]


Board: 2 copper layers, 23.0 x 30.0 mm, 27 parts (15 on the bottom side), 31 nets.

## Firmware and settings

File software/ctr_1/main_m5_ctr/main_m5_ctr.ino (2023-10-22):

//walk test2 for ee599, apr 22 2023 shuang

#include <M5Atom.h>   // http://librarymanager/All#M5Atom  https://github.com/m5stack/M5Atom
#include <FastLED.h>  // http://librarymanager/All#FastLED https://github.com/FastLED/FastLED
#include <Wire.h>
#include <arduino-timer.h>
#include "quick_math.h"

auto timer_iic = timer_create_default(); // create a timer with default settings
auto timer = timer_create_default(); // create a timer with default setting

#define FL 10
#define FR 11
#define BL 12
#define BR 13

union float_byte {
  float f;
  char c[sizeof(f)];
};

float step_timer = 0;
int step_state = 0;

float y = 0;

float test_y_coner_1;
float test_y_coner_2;
float test_x_coner_1;
float test_x_coner_2;

// gait params
float step_len = 7;
float step_fre = 1.95; //1.6 1.95

int moving_command = 0; 
// 0-forward, 1 left, 2 right

float_byte rad_tmp_fl[2];
float_byte tor_tmp_fl[2];

float_byte rad_tmp_fr[2];
float_byte tor_tmp_fr[2];

float_byte rad_tmp_bl[2];
float_byte tor_tmp_bl[2];

float_byte rad_tmp_br[2];
float_byte tor_tmp_br[2];

float rad_ori_fl[2]; //[0] - shorter link [1] - longer link
float rad_ori_fr[2];
float rad_ori_bl[2];
float rad_ori_br[2];

//ori shortlink/longlink 2.039242698, 1.458746189

float rad_offset_fl[2] = {1.3347, 2.2138};
float rad_offset_fr[2] = {1.3347, 2.0138};
float rad_offset_bl[2] = {1.3347, 2.2138};
float rad_offset_br[2] = {1.3347, 2.2138};

float test_x = 0;
float test_y = 80;

float s_s_p = 0;
float s_timer_p = 0;
float jump_timer = 0;

float fforward_torque = 0;
float roll_e = 0;
float roll_e_old = 0;
float roll_sum = 0;
float roll_k = -0.14 / 1.8; //0.14
float roll_d = -0.18 / 1.1; //0.18
float roll_i = 0;

//0.074 0.37
float fforward_torque_pitch = 0;
float pitch_e = 0;
float pitch_e_old = 0;
float pitch_k = -0.06; //0.06
float pitch_d = -0.2; //0.2
int state = 0;


//TwoWire bridge_iic(1);

void setup() {
  M5.begin(true, true, true);
  M5.IMU.Init();//init imu
  // 初期化
  //M5.begin(true, false, true);  // (Serial, I2C, NeoPixel)
  //Wire.begin(25, 21, 10000);    // 内蔵I2C 0x68(MPU6886)
  //low speed mode 10000, standard speed mode 100000, fast 400000
  Wire.begin(26, 32, 400000); //external iic

  // GPIO初期化
  //pinMode(22, INPUT); // PIN  (INPUT, OUTPUT,       )
  //pinMode(19, INPUT); // PIN  (INPUT, OUTPUT,       )
  //pinMode(23, INPUT); // PIN  (INPUT, OUTPUT,       )
  //pinMode(33, INPUT); // PIN  (INPUT, OUTPUT, ANALOG)
  //pinMode(26, INPUT); // GROVE(INPUT, OUTPUT, ANALOG)無線利用時にはANALOG利用不可, DAC出力可
  //pinMode(32, INPUT); // GROVE(INPUT, OUTPUT, ANALOG)

  // 内部ピン初期化
  //pinMode(12, OUTPUT_OPEN_DRAIN); // IR赤外線(LOWで出力)
  //digitalWrite(12, HIGH);

  // LED(0-24)
  for (int i = 0; i < 25; i++) {
    M5.dis.drawpix(i, CRGB::Blue);
  }

  timer_iic.every(5, iic_sent);
  timer.every(4, change_motion);
  //evey 10 milis, run the cycle
}

void send_to_bridge(int leg_type)
{
  Wire.beginTransmission(leg_type); // transmit to device FL
  Wire.write('r');        // sends start byte
  if (leg_type == FL)
    for (int s = 0; s < 2; s++)
      for (int i = 0; i < 4; i++)
        Wire.write(rad_tmp_fl[s].c[i]);
  else if (leg_type == FR)
    for (int s = 0; s < 2; s++)
      for (int i = 0; i < 4; i++)
        Wire.write(rad_tmp_fr[s].c[i]);
  else if (leg_type == BL)
    for (int s = 0; s < 2; s++)
      for (int i = 0; i < 4; i++)
        Wire.write(rad_tmp_bl[s].c[i]);
  else if (leg_type == BR)
    for (int s = 0; s < 2; s++)
      for (int i = 0; i < 4; i++)
        Wire.write(rad_tmp_br[s].c[i]);

  Wire.write('t');
  if (leg_type == FL)
    for (int s = 0; s < 2; s++)
      for (int i = 0; i < 4; i++)
        Wire.write(tor_tmp_fl[s].c[i]);
  else if (leg_type == FR)
    for (int s = 0; s < 2; s++)
      for (int i = 0; i < 4; i++)
        Wire.write(tor_tmp_fr[s].c[i]);
  else if (leg_type == BL)
    for (int s = 0; s < 2; s++)
      for (int i = 0; i < 4; i++)
        Wire.write(tor_tmp_bl[s].c[i]);
  else if (leg_type == BR)
    for (int s = 0; s < 2; s++)
      for (int i = 0; i < 4; i++)
        Wire.write(tor_tmp_br[s].c[i]);

  Wire.endTransmission();    // stop transmitting
}

void loop()
{
  timer.tick();
  timer_iic.tick();

  if(Serial.available())
  {
    char cc = Serial.read();
    if(cc == 'a')
      moving_command = 0;
    else if(cc == 'b')
      moving_command = 1;
    else if(cc == 'c')
      moving_command = 2;
  }
}


void leg_ik_t1(float x, float y, int leg_type)
{
  float b1_p = pow(x, 2) + pow(y, 2);
  float b1 = sqrt(b1_p);
  float a1 = atan2(y, x);
  float a0 = pi - a1;
  float b2_p = pow((l1 / 2), 2) + b1_p - l1 * b1 * cos(a0);
  float b2 = sqrt(b2_p);
  float a2 = get_tri_rad(b1, b2, l1 / 2);
  float a3 = get_tri_rad(b2, l3 + l6, l2);
  float a4 = get_tri_rad(l2, l3 + l6, b2);
  float a5 = 2 * pi - a0 - a2 - a3 - a4;
  float j1 = 1.5 * pi - a5; //longer link

  float a7 = a4 + a5 - pi;
  float p1x = x - l6 * cos(a7);
  float p1y = y - l6 * sin(a7);
  float e1_p = pow(p1x, 2) + pow(p1y, 2);
  float e1 = sqrt(e1_p);
  float c1 = atan2(p1y, p1x);
  float c2 = get_tri_rad(l5, e1, l4);
  float j2 = 0.5 * pi + c1 - c2; //shorter link

  if (leg_type == FL)
  {
    rad_ori_fl[0] = j2; //shorter link
    rad_ori_fl[1] = j1; //longer link

    rad_tmp_fl[1].f = (j1 - rad_offset_fl[1]) * -5.367; //5.167 reducer ra
    rad_tmp_fl[0].f = (j2 - rad_offset_fl[0]) * -5.367;
  }
  else if (leg_type == BR)
  {
    rad_ori_br[0] = j2; //shorter link
    rad_ori_br[1] = j1; //longer link

    rad_tmp_br[1].f = (j1 - rad_offset_br[1]) * -5.367;
    rad_tmp_br[0].f = (j2 - rad_offset_br[0]) * -5.367;
  }
  else if (leg_type == FR)
  {
    rad_ori_fr[0] = j2; //shorter link
    rad_ori_fr[1] = j1; //longer link

    rad_tmp_fr[1].f = (j1 - rad_offset_fr[1]) * 5.367;
    rad_tmp_fr[0].f = (j2 - rad_offset_fr[0]) * 5.367;
  }
  else if (leg_type == BL)
  {
    rad_ori_bl[0] = j2; //shorter link
    rad_ori_bl[1] = j1; //longer link

    rad_tmp_bl[1].f = (j1 - rad_offset_bl[1]) * 5.367;
    rad_tmp_bl[0].f = (j2 - rad_offset_bl[0]) * 5.367;
  }

  //Serial.print (j1);
  //Serial.print (" ");
  //Serial.println(j2);
}

float get_tri_rad(float ll1, float ll2, float ll3)
{
  return acos((pow(ll1, 2) + pow(ll2, 2) - pow(ll3, 2)) / (2 * ll1 * ll2));
}

bool change_motion(void *)
{
  s_s_p += 0.018 * abs(sin(s_timer_p)); //0.03 //0.018
  s_timer_p += 0.001;

  if (step_state == 0 || step_state == 2)
  {
    step_timer += 0.018 * 4 * step_fre;
  }
  else
  {
    step_timer += 0.018 * 11 * step_fre;
  }

  if (s_s_p > 2 * 3.1415926)
    s_s_p = 0;

  if (s_timer_p > 2 * 3.1415926)
    s_timer_p = 0;

  if (step_timer > 3.1415926) //half cycle
  {
    step_timer = 0;

    //change sub state
    if (step_state == 0)
      step_state = 1;
    else if (step_state == 1)
      step_state = 2;
    else if (step_state == 2)
      step_state = 3;
    else if (step_state == 3)
      step_state = 0;
  }

  float walk_height = 90;
  float step_height_gain = 2; //2
  float ground_height_gain = 0.95; //0.9
  
  if (step_state == 0)
  {
    test_y_coner_1 = walk_height - step_len * step_height_gain * sin(step_timer);
    test_x_coner_1 = 0 + step_len * cos(step_timer); //+

    test_y_coner_2 = walk_height + ground_height_gain * sin(step_timer);
    test_x_coner_2 = 0 - step_len * cos(step_timer); //-
  }
  else if (step_state == 1)
  {
    //test_y_coner_1 = 90;
    //test_x_coner_1 = 0 - step_len * cos(step_timer);
  }

  else if (step_state == 2)
  {
    test_y_coner_1 = walk_height + ground_height_gain * sin(step_timer);
    test_x_coner_1 = 0 - step_len * cos(step_timer);

    test_y_coner_2 = walk_height - step_len * step_height_gain * sin(step_timer);
    test_x_coner_2 = 0 + step_len * cos(step_timer);
  }
  else if (step_state == 3)
  {
    //test_y_coner_2 = 90;
    //test_x_coner_2 = 0 - step_len * cos(step_timer);
  }

  //ff torque

  float ground_ff = 0.15; //4.5

  if (state == 2)
  {

    for (int i = 0; i < 25; i++)
    {
      M5.dis.drawpix(i, CRGB::Red);
    }
    tor_tmp_fl[0].f = fforward_torque - 1 * fforward_torque_pitch;
    tor_tmp_fl[1].f = fforward_torque - 1 * fforward_torque_pitch;

    tor_tmp_br[0].f = -1 * fforward_torque + fforward_torque_pitch;
    tor_tmp_br[1].f = -1 * fforward_torque + fforward_torque_pitch;

    tor_tmp_bl[0].f = -1 * fforward_torque - 1 * fforward_torque_pitch;
    tor_tmp_bl[1].f = -1 * fforward_torque - 1 * fforward_torque_pitch;

    tor_tmp_fr[0].f = fforward_torque + fforward_torque_pitch;
    tor_tmp_fr[1].f = fforward_torque + fforward_torque_pitch;

    if (step_state == 0) //fr bl on ground
    {
      //kill sky foot
      tor_tmp_fl[0].f = 0;
      tor_tmp_fl[1].f = 0;

      tor_tmp_br[0].f = 0;
      tor_tmp_br[1].f = 0;

      //enhance ground foot
      tor_tmp_fr[0].f += ground_ff;
      tor_tmp_fr[1].f += ground_ff;

      tor_tmp_bl[0].f += ground_ff;
      tor_tmp_bl[1].f += ground_ff;
    }
    else if (step_state == 2) //fl br on ground
    {
      //kill sky foot
      tor_tmp_fr[0].f = 0;
      tor_tmp_fr[1].f = 0;

      tor_tmp_bl[0].f = 0;
      tor_tmp_bl[1].f = 0;

      //enhance ground foot
      tor_tmp_fl[0].f -= ground_ff;
      tor_tmp_fl[1].f -= ground_ff;

      tor_tmp_br[0].f -= ground_ff;
      tor_tmp_br[1].f -= ground_ff;
    }
  }

  else if (state == 1)
  {
    //balanced stand
    for (int i = 0; i < 25; i++) {
      M5.dis.drawpix(i, CRGB::White);
    }

    test_x_coner_1 = 0;
    test_x_coner_2 = 0;
    test_y_coner_1 = walk_height;
    test_y_coner_2 = walk_height;


    tor_tmp_fl[0].f = fforward_torque - 1 * fforward_torque_pitch;
    tor_tmp_fl[1].f = fforward_torque - 1 * fforward_torque_pitch;

    tor_tmp_br[0].f = -1 * fforward_torque + fforward_torque_pitch;
    tor_tmp_br[1].f = -1 * fforward_torque + fforward_torque_pitch;

    tor_tmp_bl[0].f = -1 * fforward_torque - 1 * fforward_torque_pitch;
    tor_tmp_bl[1].f = -1 * fforward_torque - 1 * fforward_torque_pitch;

    tor_tmp_fr[0].f = fforward_torque + fforward_torque_pitch;
    tor_tmp_fr[1].f = fforward_torque + fforward_torque_pitch;
  }
  else if (state == 0 || state == 3)
  {
    //static stand
    for (int i = 0; i < 25; i++) {
      M5.dis.drawpix(i, CRGB::Blue);
    }
    tor_tmp_fl[0].f = 0;
    tor_tmp_fl[1].f = 0;

    tor_tmp_br[0].f = 0;
    tor_tmp_br[1].f = 0;

    tor_tmp_bl[0].f = 0;
    tor_tmp_bl[1].f = 0;

    tor_tmp_fr[0].f = 0;
    tor_tmp_fr[1].f = 0;

    test_x_coner_1 = 0;
    test_x_coner_2 = 0;
    test_y_coner_1 = walk_height;
    test_y_coner_2 = walk_height;
  }

  float pitch = 0, roll = 0, yaw = 0;
  //getAhrsData pitch roll yaw using another filter
  M5.IMU.getAhrsData(&pitch, &roll, &yaw);
  if (roll < 0)
    roll = 360 + roll;

  roll_e = roll - 200; //187 178
  pitch_e = pitch - 0;

  roll_sum += roll_e;

  fforward_torque = roll_e * roll_k + roll_d * (roll_e - roll_e_old) + roll_i * roll_sum;
  fforward_torque_pitch = pitch_e * pitch_k + pitch_d * (pitch_e - pitch_e_old);

  roll_e_old = roll_e;
  pitch_e_old = pitch_e;

  M5.update();
  //Serial.printf("%.2f,%.2f\n", pitch, roll);

  if (M5.Btn.wasPressed())
  {
    if (state == 0)
      state = 1;
    else if (state == 1)
      state = 2;
    else if (state == 2)
      state = 3;
    else if (state == 3)
      state = 0;

  }
  return true;
}

bool iic_sent(void *)
{

if(moving_command == 0) // forward
{
  leg_ik_t1(-1 * test_x_coner_1 + 10, test_y_coner_1 - 4, FL);
  leg_ik_t1(-1 * test_x_coner_2 + 10, test_y_coner_2 - 4, FR);
  leg_ik_t1(1 * test_x_coner_2 + 10, test_y_coner_2 - 10, BL);
  leg_ik_t1(1 * test_x_coner_1 + 10, test_y_coner_1 - 10, BR);
}
else if(moving_command == 1) // right
{
  leg_ik_t1(1 * test_x_coner_1 + 10, test_y_coner_1 - 4, FL);
  leg_ik_t1(-1 * test_x_coner_2 + 10, test_y_coner_2 - 4, FR);
  leg_ik_t1(-1 * test_x_coner_2 + 10, test_y_coner_2 - 10, BL);
  leg_ik_t1(1 * test_x_coner_1 + 10, test_y_coner_1 - 10, BR);
}
else if(moving_command == 2) // left
{
  leg_ik_t1(-1 * test_x_coner_1 + 10, test_y_coner_1 - 4, FL);
  leg_ik_t1(1 * test_x_coner_2 + 10, test_y_coner_2 - 4, FR);
  leg_ik_t1(1 * test_x_coner_2 + 10, test_y_coner_2 - 10, BL);
  leg_ik_t1(-1 * test_x_coner_1 + 10, test_y_coner_1 - 10, BR);
}

  //leg_inv_dny(rad_ori_fl[0], rad_ori_fl[1], 0, -0.02, FL);

  send_to_bridge(FL);
  send_to_bridge(FR);
  send_to_bridge(BL);
  send_to_bridge(BR);

  return true;

}

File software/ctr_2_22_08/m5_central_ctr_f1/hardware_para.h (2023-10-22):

#ifndef _HARDWARE_PARA__
#define _HARDWARE_PARA__

#define pi  3.14159265358979323846

//leg types
#define FL  0
#define FR  1
#define BL  2
#define BR  3

//leg link length
#define LEG_LINK_LEN_L1 29.1
#define LEG_LINK_LEN_L2 48
#define LEG_LINK_LEN_L3 38
#define LEG_LINK_LEN_L4 60
#define LEG_LINK_LEN_L5 33
#define LEG_LINK_LEN_L6 34.5

//reducer para
#define REDUCER_RATIO 5.367

//joint offset
#define J_OFFSET_0 1.458746189
#define J_OFFSET_1 2.039242698

//body size
#define BODY_WIDTH 10
#define BODY_LENGTH 10

#endif

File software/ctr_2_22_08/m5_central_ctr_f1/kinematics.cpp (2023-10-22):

#include "kinematics.h"

leg::leg(int _leg_type)
{
    //hardware para setup
    l1 = LEG_LINK_LEN_L1;
    l2 = LEG_LINK_LEN_L2;
    l3 = LEG_LINK_LEN_L3;
    l6 = LEG_LINK_LEN_L6;
    l5 = LEG_LINK_LEN_L5;
    l4 = LEG_LINK_LEN_L4;
    leg_type = _leg_type;

    rad_offset[1] = J_OFFSET_1;
    rad_offset[0] = J_OFFSET_0;

    reducer_ratio = REDUCER_RATIO;
}

int leg::leg_ik()
{
    float y = local_foot_cod_tar[1] * -1;
    float x = local_foot_cod_tar[0];
    if (leg_type == FL || leg_type == BL)
        x *= -1;

    float b1_p = pow(x, 2) + pow(y, 2);
    float b1 = sqrt(b1_p);
    float a1 = atan2(y, x);
    float a0 = pi - a1;
    float b2_p = pow((l1 / 2), 2) + b1_p - l1 * b1 * cos(a0);
    float b2 = sqrt(b2_p);
    float a2 = get_tri_rad(b1, b2, l1 / 2);
    float a3 = get_tri_rad(b2, l3 + l6, l2);
    float a4 = get_tri_rad(l2, l3 + l6, b2);
    float a5 = 2 * pi - a0 - a2 - a3 - a4;
    //rad at longer link
    joint_rad_arr[0] = 1.5 * pi - a5;

    float a7 = a4 + a5 - pi;
    float p1x = x - l6 * cos(a7);
    float p1y = y - l6 * sin(a7);
    float e1_p = pow(p1x, 2) + pow(p1y, 2);
    float e1 = sqrt(e1_p);
    float c1 = atan2(p1y, p1x);
    float c2 = get_tri_rad(l5, e1, l4);
    //rad at short link
    joint_rad_arr[1] = 0.5 * pi + c1 - c2;

    if (leg_type == FL || leg_type == BR)
    {
        motor_rad_arr[1] = (joint_rad_arr[0] - rad_offset[0]) * -1 * reducer_ratio;
        motor_rad_arr[0] = (joint_rad_arr[1] - rad_offset[1]) * -1 * reducer_ratio;
    }
    else if (leg_type == FR || leg_type == BL)
    {
        motor_rad_arr[1] = (joint_rad_arr[0] - rad_offset[0]) * reducer_ratio;
        motor_rad_arr[0] = (joint_rad_arr[1] - rad_offset[1]) * reducer_ratio;
    }

    return 0;
}

float leg::get_tri_rad(float ll1, float ll2, float ll3)
{
    return acos((pow(ll1, 2) + pow(ll2, 2) - pow(ll3, 2)) / (2 * ll1 * ll2));
}

int leg::get_local_foot_cod_tar(vec3d &foot_root, vec3d &foot_end)
{
    //considering this is a model with 2dof leg
    //dont consider 3d cod x
    vec3d tmp = foot_end - foot_root;
    local_foot_cod_tar[0] = tmp.vec[1]; //local x<->3d y
    local_foot_cod_tar[1] = tmp.vec[2]; //local y<->3d z

    return 0;
}

body::body()
{
    leg_fl = new leg(FL);
    leg_fr = new leg(FR);
    leg_bl = new leg(BL);
    leg_br = new leg(BR);

    sender = new bridge_sender;

    body_width = BODY_WIDTH;
    body_length = BODY_LENGTH;
}

int body::init_body_mat()
{
    leg_root_fl.vec[0] = -1 * body_width / 2; //width-x
    leg_root_fl.vec[1] = body_length / 2;

    leg_root_fr.vec[0] = body_width / 2;
    leg_root_fr.vec[1] = body_length / 2;

    leg_root_bl.vec[0] = -1 * body_width / 2;
    leg_root_bl.vec[1] = -1 * body_length / 2;

    leg_root_br.vec[0] = body_width / 2;
    leg_root_br.vec[0] = -1 * body_length / 2;

    leg_root_fl = leg_root_fl + body_pos_vec;
    leg_root_fr = leg_root_fr + body_pos_vec;
    leg_root_bl = leg_root_bl + body_pos_vec;
    leg_root_br = leg_root_br + body_pos_vec;

    return 0;
}

int body::refresh_body_mat()
{
    //cal rot point
    leg_root_fl = body_rot_mat * leg_root_fl;
    leg_root_fr = body_rot_mat * leg_root_fr;
    leg_root_bl = body_rot_mat * leg_root_bl;
    leg_root_br = body_rot_mat * leg_root_br;

    //translate
    leg_root_fl = leg_root_fl + body_pos_vec;
    leg_root_fr = leg_root_fr + body_pos_vec;
    leg_root_bl = leg_root_bl + body_pos_vec;
    leg_root_br = leg_root_br + body_pos_vec;

    return 0;
}

int body::body_ik()
{
    refresh_body_mat();
    //trans 3d foot cod to local foot cod
    leg_fl->get_local_foot_cod_tar(leg_root_fl, leg_end_fl);
    leg_fr->get_local_foot_cod_tar(leg_root_fr, leg_end_fr);
    leg_bl->get_local_foot_cod_tar(leg_root_bl, leg_end_bl);
    leg_br->get_local_foot_cod_tar(leg_root_br, leg_end_br);

    leg_fl->leg_ik();
    leg_fr->leg_ik();
    leg_bl->leg_ik();
    leg_br->leg_ik();

    return 0;
}

int body::send_to_leg()
{
    sender->iic_send(leg_fl->leg_type, leg_fl->motor_rad_arr, leg_fl->torque_feedforward_to_motor);
    sender->iic_send(leg_fr->leg_type, leg_fr->motor_rad_arr, leg_fr->torque_feedforward_to_motor);
    sender->iic_send(leg_bl->leg_type, leg_bl->motor_rad_arr, leg_bl->torque_feedforward_to_motor);
    sender->iic_send(leg_br->leg_type, leg_br->motor_rad_arr, leg_br->torque_feedforward_to_motor);

    return 0;
}

int body::set_body_pos_tar(float _x, float _y, float _z)
{
    body_pos_vec.vec[0]=_x;
    body_pos_vec.vec[1]=_y;
    body_pos_vec.vec[2]=_z;
    return 0;
}

int body::set_body_rot_tar(float _pitch, float _roll, float _yaw)
{
    body_rot_angle_tar.vec[0]=_pitch;
    body_rot_angle_tar.vec[1]=_roll;
    body_rot_angle_tar.vec[2]=_yaw;

    body_rot_mat.gen_rotation(body_rot_angle_tar.vec);

    return 0;
}

int body::get_body_rot_now(float _pitch_n, float _roll_n, float _yaw_n)
{
    body_rot_angle_now.vec[0]=_pitch_n;
    body_rot_angle_now.vec[1]=_roll_n;
    body_rot_angle_now.vec[2]=_yaw_n;
    return 0;
}

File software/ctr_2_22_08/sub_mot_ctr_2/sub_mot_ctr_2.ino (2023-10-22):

/**

   Position/angle motion control example
   Steps:
   1) Configure the motor and magnetic sensor
   2) Run the code
   3) Set the target angle (in radians) from serial terminal

*/
#include <SimpleFOC.h>

int led = 10;

// magnetic sensor instance - SPI
MagneticSensorI2C sensor = MagneticSensorI2C(AS5600_I2C);
// magnetic sensor instance - MagneticSensorI2C
//MagneticSensorI2C sensor = MagneticSensorI2C(AS5600_I2C);
// magnetic sensor instance - analog output
// MagneticSensorAnalog sensor = MagneticSensorAnalog(A1, 14, 1020);

// BLDC motor & driver instance
BLDCMotor motor = BLDCMotor(7);
BLDCDriver3PWM driver = BLDCDriver3PWM(5, 9, 6, 7);
// Stepper motor & driver instance
//StepperMotor motor = StepperMotor(50);
//StepperDriver4PWM driver = StepperDriver4PWM(9, 5, 10, 6,  8);

// angle set point variable
float target_angle = 0;
// instantiate the commander
Commander command = Commander(Serial);
void onMotion(char* cmd) {
  command.motion(&motor, cmd);
}

void setup() {
  pinMode(led, OUTPUT);

  // initialise magnetic sensor hardware
  sensor.init();
  // link the motor to the sensor
  motor.linkSensor(&sensor);

  // driver config
  // power supply voltage [V]
  driver.voltage_power_supply = 12;
  driver.init();
  // link the motor and the driver
  motor.linkDriver(&driver);

  // choose FOC modulation (optional)
  motor.foc_modulation = FOCModulationType::SpaceVectorPWM;

  // set motion control loop to be used
  motor.controller = MotionControlType::angle;

  // contoller configuration
  // default parameters in defaults.h

  // velocity PI controller parameters
  // after mod, the velocity pid is position-torque pid
  
  motor.PID_velocity.P = 8.1;//0.05;//0.085;//0.12 //7.1
  motor.PID_velocity.I = 0.1;//0.8;//15
  motor.PID_velocity.D = 0.02;//0.015;//0;//0.001 //0.029

  //disabele ramp
  motor.PID_velocity.output_ramp = -1;
  
  // maximal voltage to be set to the motor
  motor.voltage_limit = 12;

  // velocity low pass filtering time constant
  // the lower the less filtered
  //motor.LPF_velocity.Tf = 0.005;

  // angle P controller 
  //motor.P_angle.P = 0.05;//80;
  //motor.P_angle.I = 0;
  //motor.P_angle.D = 0;//0.008;
  // maximal velocity of the position control
  motor.velocity_limit = 50;

  //motor.motion_downsample = 2;

  // use monitoring with serial
  Serial.begin(115200);
  // comment out if not needed
  motor.useMonitoring(Serial);


  // initialize motor
  motor.init();
  // align sensor and start FOC
  motor.initFOC();

  // add target command T
  command.add('M', onMotion, "motion control");

  Serial.println(F("Motor ready."));
  Serial.println(F("Set the target angle using serial terminal:"));

  //offset, measured for each joint, change with different joints
  motor.sensor_offset = -5;

  ////////////////////////////////////////////////////////////////
  digitalWrite(led, HIGH);
  _delay(1000);

  //motor.disable();

  //motor.disable();
  //motor.target = motor.shaftAngle();
  //calibration process, reset shaft angle

  /*
  float shaft_ang_tmp = 0;
  for(int s=0;s<10;s++)
  {
    shaft_ang_tmp += motor.shaftAngle();
    Serial.println(motor.shaftAngle());
    _delay(20);
  }
  shaft_ang_tmp /= 10.0;
  motor.sensor_offset = shaft_ang_tmp;
  //motor.enable();
  digitalWrite(led, HIGH);
  _delay(500);
*/

}


void loop() {

  // main FOC algorithm function
  // the faster you run this function the better
  // Arduino UNO loop  ~1kHz
  // Bluepill loop ~10kHz
  
  motor.loopFOC();

  // Motion control function
  // velocity, position or voltage (defined in motor.controller)
  // this function can be run at much lower frequency than loopFOC() function
  // You can also use motor.move() and set the motor.target in the code
  //shaft_ang_tmp - offset, target - ang setpoint, shift_angle - current router angle
  
  motor.move();


  // function intended to be used with serial plotter to monitor motor variables
  // significantly slowing the execution down!!!!
  //motor.monitor();

  // user communication
  command.run();

  //Serial.println(motor.shaft_angle);
}

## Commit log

2023-10-22 add: 1021 open docu
    [0402.0004.ipt, 0402.ipt, 0402_MIR.0001.ipt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]
2023-10-22 add: 1022 clean gcode
    [2test_bench_conn_1.stl, body_conn_1.stl, body_conn_2.stl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]

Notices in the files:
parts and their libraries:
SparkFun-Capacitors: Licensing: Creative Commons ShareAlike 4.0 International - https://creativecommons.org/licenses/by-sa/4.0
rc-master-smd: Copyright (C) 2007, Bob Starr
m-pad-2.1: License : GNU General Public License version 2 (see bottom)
